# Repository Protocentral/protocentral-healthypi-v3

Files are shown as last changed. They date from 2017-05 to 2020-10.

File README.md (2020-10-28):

# ProtoCentral HealthyPi v3 HAT for Raspberry Pi

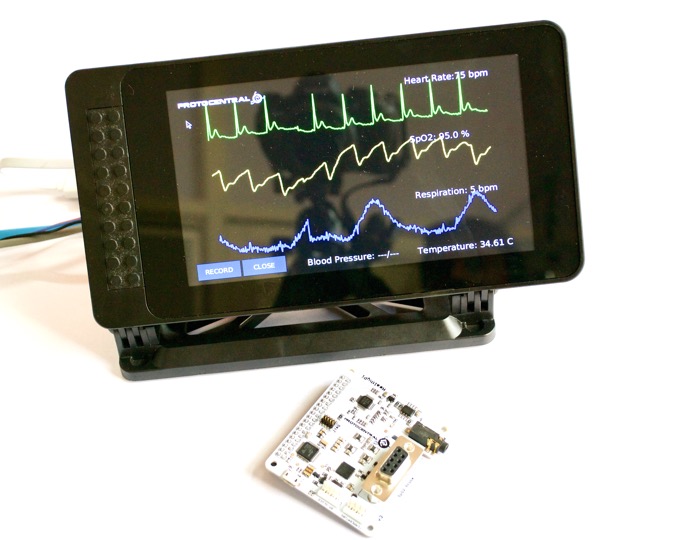
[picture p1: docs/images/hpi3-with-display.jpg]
Healthy Pi v3 HAT


HealthyPi is the first fully open-source, full-featured vital sign monitor. Using the Raspberry Pi as its computing and display platform, the HealthyPi add-on HAT turns the Raspberry Pi into a vital sign monitoring system.

If you don't already have one, you can now buy HealthyPi from any of the following places:

* [Crowd Supply](https://www.crowdsupply.com/protocentral/healthypi-v3)
* [ProtoCentral India (Worldwide)](https://www.protocentral.com/open-source-health/1252-healthypi-v3-complete-kit-includes-raspberry-pi.html)
* [DigiKey](https://www.digikey.in/product-detail/en/crowd-supply-inc/CS-HEALTHYPI-01/1848-1035-ND)
* [Mouser](https://www.mouser.in/ProductDetail/392-CS-HEALTHYPI-01)

Repository Contents
-------------------
* **/firmware** - Atmel studio  and aduino example sketches.
* **/Hardware** - All Eagle design files (.brd, .sch)
* **/extras** - includes the datasheet
* **/gui** - HealthyPi GUI for Raspberry Pi and PC
* **/docs** - Documentation

Getting Started (On Raspberry Pi):
----------------------------------

### For getting started videos and tutorials, please go to [http://healthypi.protocentral.com](http://healthypi.protocentral.com)

Mount ProtoCentral's HealthyPi-v3 HAT carefully onto the Raspberry Pi Board's GPIO Pins. Connect this setup with the Raspberry Pi's Display or a HDMI Monitor. The HAT communicates with Raspberry Pi using UART interface on the GPIO pin header. Connect the ECG electrodes and SPO2 Probe to the ProtoCentral's Healthy PI Hat.

It's now easy to get started with our brand-new installation script. Just follow the following steps on your Raspberry Pi.

To start, open up the terminal window (Menu -> Accessories -> Terminal) on Raspbian running on your Raspberry Pi:

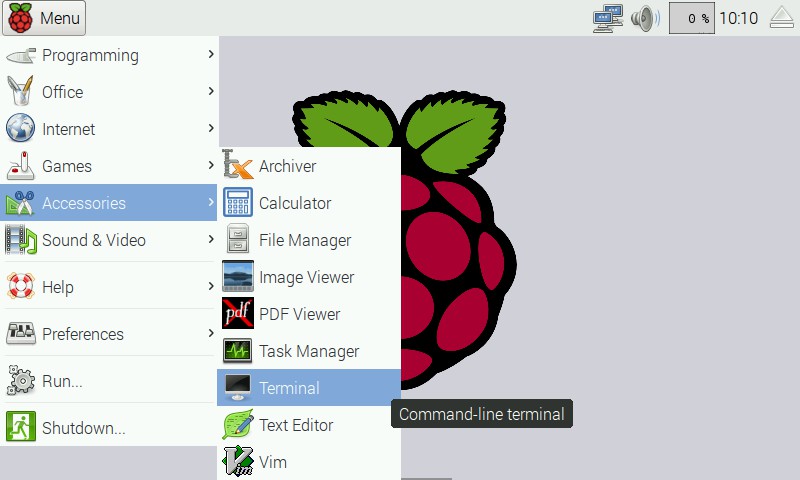
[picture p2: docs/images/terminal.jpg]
Open the terminal


In the terminal window, type the following lines.

```bash
curl -sS http://pi.protocentral.com/hpi3.sh | sudo bash
```

It really is as simple as that !!

This code will install all the required overlays, configuration and application files to get the Healthy Pi up and running.

After the script reboots, you should be able to see the GUI display on the screen

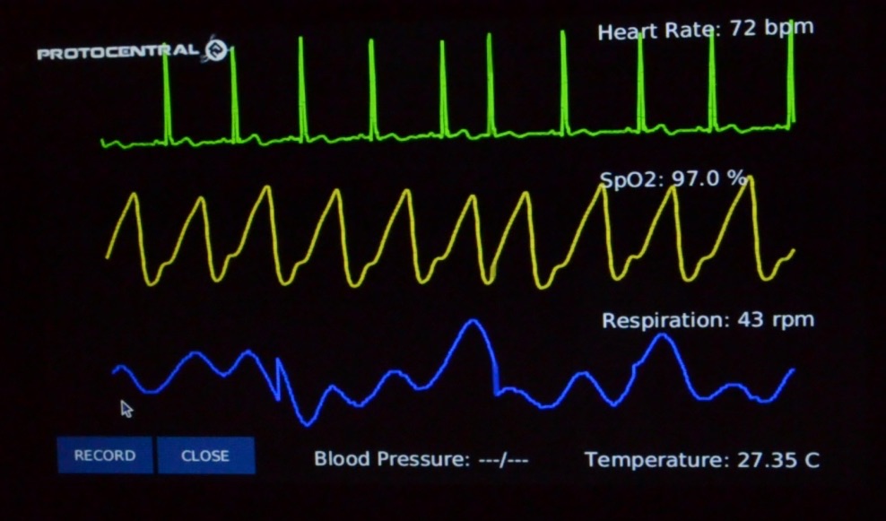
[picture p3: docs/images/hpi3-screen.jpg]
GUI in Processing


### This completes the install!

If the above script does not work for you and would like to do a manual installation or would like to customize the code, check out [Advanced HealthyPi] (/docs/advanced-healthypi.md).

Using the HealthyPi GUI on Windows, MacOS and Linux
---------------------------------------------------
The HealthyPi board now streams the same data on the on-board USB port. This allows you to get the same data that goes to the Raspberry Pi, now on your desktop PC as well.

Java 8 is required on all platforms for running the processing-based GUI application. You can download Java for your platform from the following link.

[https://java.com/en/download/](https://java.com/en/download/)

#### Installing drivers (only for Windows)

HealthyPi uses the same drivers as an Arduino Zero. Once plugged in to the USB port, the device would be recognized as an "Unknown Device". You can locate the device is the Windows Device Manager and manually install the drivers provided in the "drivers" folder in the Windows Executable ZIP archive provided.

MacOS and Linux do not need any drivers to be installed.

### Processing GUI Installation

Download the zip file containing the executable files from the releases section for 32-bit/64-bit Windows. If you do not know if you have a 64-bit or 32-bit computer, please download the 32-bit version.

[Download the latest GUI for HealthyPi](https://github.com/Protocentral/protocentral-healthypi-v3/releases/latest)

Simply download the appropriate file for your operating system, unzip the contents and run the executable program contained in it.

### For more documentation, videos and tutorials, please go to [http://healthypi.protocentral.com](http://healthypi.protocentral.com)

License Information
===================

This product is open source! Both, our hardware and software are open source and licensed under the following licenses:

Hardware
---------

**All hardware is released under [Creative Commons Share-alike 4.0 International](http://creativecommons.org/licenses/by-sa/4.0/).**


You are free to:

* Share — copy and redistribute the material in any medium or format
* Adapt — remix, transform, and build upon the material for any purpose, even commercially.
The licensor cannot revoke these freedoms as long as you follow the license terms.

Under the following terms:

* Attribution — You must give appropriate credit, provide a link to the license, and indicate if changes were made. You may do so in any reasonable manner, but not in any way that suggests the licensor endorses you or your use.
* ShareAlike — If you remix, transform, or build upon the material, you must distribute your contributions under the same license as the original.

Software
--------

**All software is released under the MIT License(http://opensource.org/licenses/MIT).**

THE SOFTWARE IS PROVIDED "AS IS", WITHOUT WARRANTY OF ANY KIND, EXPRESS OR IMPLIED, INCLUDING BUT NOT LIMITED TO THE WARRANTIES OF MERCHANTABILITY, FITNESS FOR A PARTICULAR PURPOSE AND NONINFRINGEMENT. IN NO EVENT SHALL THE AUTHORS OR COPYRIGHT HOLDERS BE LIABLE FOR ANY CLAIM, DAMAGES OR OTHER LIABILITY, WHETHER IN AN ACTION OF CONTRACT, TORT OR OTHERWISE, ARISING FROM, OUT OF OR IN CONNECTION WITH THE SOFTWARE OR THE USE OR OTHER DEALINGS IN THE SOFTWARE.

Please check [*LICENSE.md*](LICENSE.md) for detailed license descriptions.

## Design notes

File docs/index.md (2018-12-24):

---
layout: page
homepage: true
---

Healthy Pi Hat

HealthyPi is the first fully open-source, full-featured vital sign monitor. Using the Raspberry Pi as its computing and display platform, the HealthyPi add-on HAT turns the Raspberry Pi into a vital sign monitoring system.

If you don't already have one, you can now buy HealthyPi from any of the following places:

* [Crowd Supply](https://www.crowdsupply.com/protocentral/healthypi-v3)
* [ProtoCentral USA](https://protocentral.us/products/13-healthypi-v3-hat-kit-for-raspberry-pi.html)
* [ProtoCentral India (Worldwide)](https://www.protocentral.com/open-source-health/1252-healthypi-v3-complete-kit-includes-raspberry-pi.html)
* [DigiKey](https://www.digikey.in/product-detail/en/crowd-supply-inc/CS-HEALTHYPI-01/1848-1035-ND)
* [Mouser](https://www.mouser.in/ProductDetail/392-CS-HEALTHYPI-01)

# Repository Contents
-------------------
* **/firmware** - Atmel studio and Arduino example sketches.
* **/Hardware** - All Eagle design files (.brd, .sch)
* **/extras** - includes the datasheet
* **/gui** - HealthyPi GUI for Raspberry Pi and PC
* **/docs** - Additional Documentation

# Getting Started with HealthyPi

The HealthyPi was designed with not just one application in mind, but a variety of them. While it does function as a vital sign monitor for traditional patient monitoring applications, it can also be used for several other applications. You can use it with a Raspberry Pi using a display; use it with a Raspberry Pi with the official touchscreen using our “Complete Kit,” or you can use it standalone by connecting it to any computer’s USB port. The software is compatible across all platforms.

## Getting started with the HealthyPi Complete Kit

If you have purchased the "HealthyPi Complete Kit", then it would already come with a Raspberry Pi and microSD storage with all the HealthyPi software pre-loaded and configured on it. Just plug it in and it should work.

You would still need to assemble the display enclosure and the display stand for the provided [SmartiPi Touch Case](https://smarticase.com/collections/all/products/smartipi-touch). The SmartiPi Touch that comes included with the HealthyPi kit is already partly assembled. Check out the below video for instructions on how to assemble the kit.

<iframe src="https://player.vimeo.com/video/225759990" width="640" height="360" frameborder="0" webkitallowfullscreen mozallowfullscreen allowfullscreen></iframe>

## Getting started with HealthyPi on Raspberry Pi

If you have a Raspberry Pi setup already available, just follow the following steps on your Raspberry Pi. You will need a monitor and a keyboard/mouse and the Raspberry Pi should be running Raspbian before proceeding with HealthyPi installation. To find out how to install Raspbian check out this great tutorial on Raspberry Pi's official site.

The following video shows you how to connect the HealthyPi to a Raspberry Pi.

<iframe src="https://player.vimeo.com/video/226236581" width="640" height="360" frameborder="0" webkitallowfullscreen mozallowfullscreen allowfullscreen></iframe>

After completing the steps shown in the video, open up the terminal window (Menu -> Accessories -> Terminal) on Raspbian running on your Raspberry Pi:

Open the terminal

In the terminal window, type the following lines.

```bash
curl -sS http://pi.protocentral.com/hpi3.sh | sudo bash
```

Follow the instructions shown carefully, this will download and install all that is required to get the HealthyPi running.

It really is as simple as that. This code will install all the required overlays, configuration and application files to get the Healthy Pi up and running.

After the script reboots your Raspberry Pi, you should be able to see the GUI display the sensor outputs in real-time on the screen.

GUI in Processing

**This completes the install!**

## Getting started with the HealthyPi GUI on Windows, MacOS and Linux

The HealthyPi board now streams the same data on the on-board USB port. This allows you to get the same data that goes to the Raspberry Pi, now on your desktop PC as well.

<iframe src="https://player.vimeo.com/video/225754981" width="640" height="360" frameborder="0" webkitallowfullscreen mozallowfullscreen allowfullscreen></iframe>

*Java 8 is required on all platforms for running the processing-based GUI application. You can download Java for your platform from the following link.*

[https://java.com/en/download/](https://java.com/en/download/)

### Installing drivers (only for Windows)

HealthyPi uses the same drivers as an Arduino Zero. Once plugged in to the USB port, the device would be recognized as an "Unknown Device". You can locate the device is the Windows Device Manager and manually install the drivers provided in the "drivers" folder in the Windows Executable ZIP archive provided.

MacOS and Linux do not need any drivers to be installed.

### Processing GUI Installation

Download the zip file containing the executable files from the following links for 32-bit/64-bit Windows. If you do not know if you have a 64-bit or 32-bit computer, try with the 32-bit version.

[Download the latest release here](https://github.com/Protocentral/protocentral-healthypi-v3/releases/latest)

Simply download the appropriate file for your operating system, unzip the contents and run the executable program contained in it. On desktop operating systems, you will have to choose the correct port name assigned to the HealthyPi by USB. Simply select the port from the dropdown on the top and port should be opened.

*Note: On MacOS, if you see an error saying "app is damaged", please follow the steps given in https://support.apple.com/en-us/HT202491 .This is a known issue with Processing on MacOS.*

# Connecting the sensors

## Connecting the ECG/Respiration Electrodes

A 3-electrode cable along with a standard stereo jack is provided along with the shield to connect the electrodes to the  board.
The other side of the electrode connector would connect to snap-on electrodes attached to the body. For testing purposes, you can use an ECG simulator to provide inputs to the board.

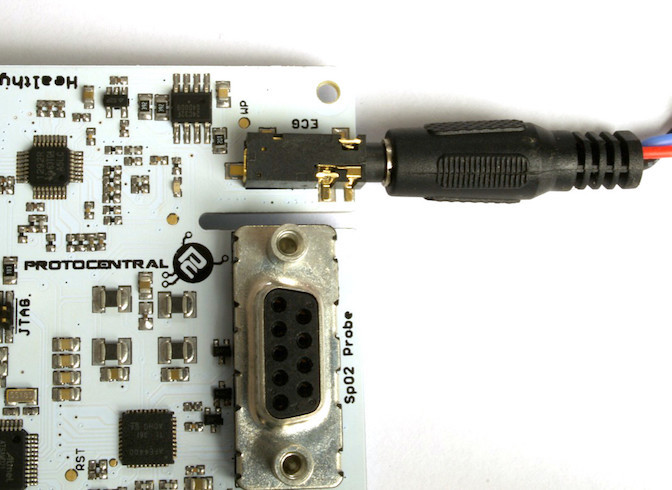
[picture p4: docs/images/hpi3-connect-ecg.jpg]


**Important Warning:**
When connecting the electrodes to the body, it is safer to disconnect the mains power source to the Arduino. For example, if  you are using the Arduino along with a laptop, disconnecting the battery charger from the laptop would be a safe option.

Place the electrodes on the body in these positions to get the best signal. However, placing it in other positions on the chest would work as well with differing ECG signal patterns. For getting respiration using the [Impedance Pneumography](http://www.ti.com/lit/an/sbaa181/sbaa181.pdf), it's best to wear them on the chest as given in the figure below to get the best signal.

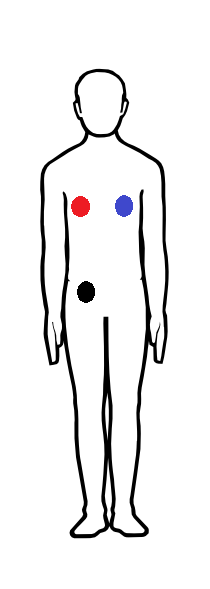
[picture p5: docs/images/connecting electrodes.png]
Wearing the Electrode


## Connecting the Pulse Oximetry Probe

[Pulse oximetry] is an optical method of non-invasively measuring the oxygen content in the blood. This is achieved with the help of a finger-clip probe that contains some LEDs on one side of the clip and a photo-detector on the other side.

The LEDs emit light in the red and IR wavelengths. Some of these are absorbed by the blood and the rest is transmitted through to the other side of  the finger, which is is picked up by the photo-detector. The Pulse Oximetry front-end measures this variance in the transmitted light intensity to display the Photoplethysmogram (PPG) signal. SpO2 is a computed value derived from the Red and IR PPG signal.

To start measuring, simply plug-in the provided SpO2 finger-clip probe to the DB9 connector on the HealthyPi main board. If the probe is properly plugged in, you should see a Red glow inside the probe.

[Photo of plugging in the DB9 connector]

## Connecting the temperature sensor

A digital human body temperature sensor based on the MAX30205 from Maxim Integrated is provided. This sensor provides direct, calibrated temperature values over a digital I2C interface. This comes pre-connected with the HealthyPi through a simple screw-terminal based connector and a cable for maximum flexibility.

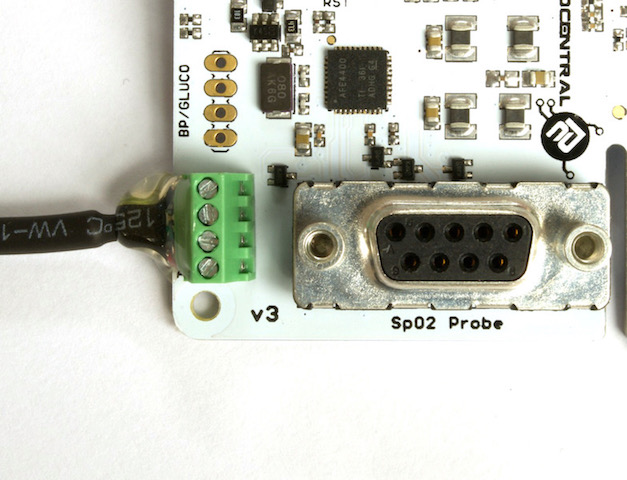
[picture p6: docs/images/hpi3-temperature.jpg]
Temperature sensor


If you ever remove the sensor and wish to connect it back to the HealthyPi, please wire it in the sequence shown in the following picture.

[Photo of temperature sensor connector with color codes]

# Updating the firmware

It is important to always keep your firmware up-to-date for best results. We keep adding changes, bug fixes and enhancements as and when we do updates. HealthyPi will be continued to be developed and new features added.

Be on the lookout for new firmware releases on our Github releases page at:

https://github.com/Protocentral/protocentral-healthypi-v3/releases

To install the new firmware and/or try out your own firmware, check out new [Guide to Firmware Upgrades](firmware-upgrades.md).

# Streaming Packet Format

The HealthyPi sends data out on the serial port in the following packet format.

 Offset| Byte Value                 | Description   
--------|---------------------------|---------------
 0     | 0x0A                       | Start of frame
 1     | 0xFA                       | Start of frame
 2     | Payload Size LSB           |               
 3     | Payload Size MSB           |               
 4     | Protocol version           | (currently 0x02)
 5-6   | ECG Value                  | Signed int 16,LSB first
 7-8   | Respiration Value          | Signed int 16,LSB first
 9-12  | PPG IR Value               | Signed int 32, LSB first
 13-16 | PPG Red Value              | Signed int 32, LSB first
 17-18 | Temperature                | Signed int 16, LSB first
 19    | Respiration Rate           | Unsigned int 8
 20    | SpO2                       | Unsigned int 8
 21    | Heart Rate                 | Unsigned int 8
 21-23 | BP (not implemented)       | Not implemented yet
 24    | SpO2 and ECG lead status   |
 25    | 0x00                       | Footer
 26    | 0x0B                       | End of Frame

# License Information

This product is open source! Both, our hardware and software are open source and licensed under the following licenses:

## Hardware

All hardware is released under [Creative Commons Share-alike 4.0 International](http://creativecommons.org/licenses/by-sa/4.0/).



## Software

All software is released under the MIT License(http://opensource.org/licenses/MIT).

Please check [*LICENSE.md*](LICENSE.md) for detailed license descriptions.

THE SOFTWARE IS PROVIDED "AS IS", WITHOUT WARRANTY OF ANY KIND, EXPRESS OR IMPLIED, INCLUDING BUT NOT LIMITED TO THE WARRANTIES OF MERCHANTABILITY, FITNESS FOR A PARTICULAR PURPOSE AND NON-INFRINGEMENT. IN NO EVENT SHALL THE AUTHORS OR COPYRIGHT HOLDERS BE LIABLE FOR ANY CLAIM, DAMAGES OR OTHER LIABILITY, WHETHER IN AN ACTION OF CONTRACT, TORT OR OTHERWISE, ARISING FROM, OUT OF OR IN CONNECTION WITH THE SOFTWARE OR THE USE OR OTHER DEALINGS IN THE SOFTWARE.

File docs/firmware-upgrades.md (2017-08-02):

# Upgrading HealthyPi v3 Firmware

All HealthyPi v3 boards come **pre-installed** with the Arduino Zero bootloader and the current release Arduino-based code. This means that you no longer need a JTAG programmer or Atmel Studio or similar toolchain to customize the code on the SAMD21 microcontroller on the board.

In addition, the new Arduino-based HealthyPi v3 firmware now **streams over USB** the same data sent to the Raspberry Pi's UART pins. This now means that the HealthyPi works not just with a Raspberry Pi, but any Windows/MAC/Linux machine that supports Java and Processing.

To upgrade the firmware, simply following these steps to get started:

### Step 1: Install the Arduino IDE

Download and install the latest version of the Arduino IDE for your corresponding platform from the following Page.

[Arduino Downloads Page at https://www.arduino.cc/en/Main/Software](https://www.arduino.cc/en/Main/Software)

### Step 2: Install support for the Arduino Zero (Atmel SAMD21 MCU)

Plug in the HealthyPI to your PC through the USB cable provided and follow the instructions on Arduino website for getting started with the Arduino Zero. When connected to a computer, your HealthyPi will behave exactly like an Arduino Zero does.

[Install support for Arduino Zero](https://www.arduino.cc/en/Guide/ArduinoZero)

### Step 3: Open the HealthyPi code in Arduino

Download the latest code from the releases section of the HealthyPi v3 Github repository at https://github.com/Protocentral/protocentral-healthypi-v3/releases

From this page, download the "healthypi-firmware.zip" file under the **latest available release**.

Once downloaded, unzip the file and in Arduino open the ".ino" file from the unzipped folder.

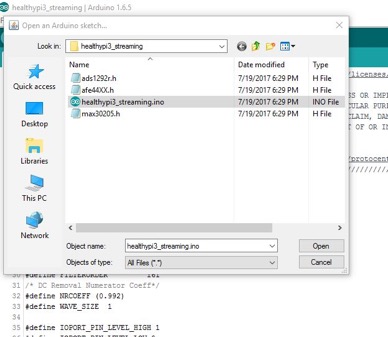
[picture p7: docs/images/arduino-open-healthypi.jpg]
Open in Arduino


### Step 4: Upload the program

Click the "Upload" button on the Arduino IDE to compile and upload the firmware.

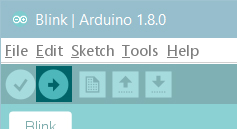
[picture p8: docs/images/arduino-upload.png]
Upload to Arduino


If all goes well, you should see an "Done Uploading" or similar message.

### Step 5: Start hacking

Feel to hack away at the code and try out things. Submit an issue on our Github site (https://github.com/Protocentral/protocentral-healthypi-v3/issues) if you think you've run into a bug or if there's something you'd like to see added.

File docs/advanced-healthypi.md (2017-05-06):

Advanced HealthyPi
==================
This section is for those who want to do a manual installation of HealthyPi, those who want to modify with the code and generally play with the hardware.

For the simple way to setup HealthyPi on Raspberry Pi, check out the [getting started guide](https://github.com/protocentral/healthypi).

You can buy [HealthyPi at ProtoCentral](https://www.protocentral.com/healthypi)

Setting up Raspberry Pi for UART Communication
----------------------------------------------
The following are the steps involved to get Raspberry Pi ready for a patient monitor.

###Step 1 : Install and Update the OS

* Install the Raspbian OS in Raspberry Pi. The image file can be downloaded from the [Raspberry Pi's official website](https://www.raspberrypi.org/downloads/).

* Once the installation finishes, update the system with the following command in the Terminal:
		
		sudo apt-get update
		sudo apt-get upgrade

###Step 2 : Enable the UART0 device tree overlay

As the ProtoCentral's Healthy Pi Hat communicates with the Raspberry Pi board via GPIO 14/15 which on the Model B, B+ and Pi2 is mapped to UART0. However on the Pi3 these pins are mapped to UART1 since UART0 is now used for the bluetooth module. As UART1 is not stable because it is dependent to clock speed which can change with the CPU load, we have to disable the Bluetooth module and map UART1 back to UART0 (tty/AMA0).

* Run the following command

		sudo nano /boot/config.txt

* Add this line to the end of the file

		dtoverlay=pi3-miniuart-bt

###Step 3 : Disable Serial command line console

* To disable the Serial Console edit the file using

		sudo nano /boot/cmdline.txt 

* Remove the word phase "console=serial0,115200" or "console=ttyAMA0,115200".

* Save the file and close

###Step 4 : Reboot your Raspberry Pi

* Now your Pi is ready to integrate with ProtoCentral's Healthy Pi Hat.

HealthyPi GUI based on Processing
---------------------------------

[Processing](https://processing.org/) has been used to develop the visualization software for the HealthyPi. 

Processing is an open source framework based on Java. The following are the steps to get the visualization software ready for patient monitor:

###Step 1 : Download Processing IDE for your HOST COMPUTER operating system

a. Latest Version of the Processing IDE can be downloaded from the following link:

[Download Processing](https://processing.org/download/?processing)

b. Unzip and install the file once downloaded.

###Step 2 : Download the Processing code for the HealthyPi GUI

a. Download the necessary files & directories or clone to your desktop from GitHub.

b. Unzipping the archive should make a folder by name HealthyPi that contains the visualisation code.

c. Locate the Processing sketchbook directory on your computer. This should have been created automatically when you installed processing. Depending on your operating system, the path will be as follows:

* On Windows : C:/My Documents/Processing
* On MAC : /Users/your_user_name/Documents/Processing
* On Linux : /Home/your_user_name/sketchbook/

**Note:** This directory appears as "Processing" on Windows/Mac, and goes by the name "Sketchbook" on Linux. Create a subdirectory by name "libraries if one doesn't exist already.

d. From the above mentioned "HealthyPi" directory Copy/Move the contents of the HealthyPi/Processing/HealthyPi folder to the Processing sketchbook directory which is also mentioned above (Locate the Processing sketchbook)

e. Finally, copy the "controlP5 & G4P" folders from HealthyPi/Processing/libraries/ and paste them into the libraries directory of your Processing sketchbook.

###Step 3 : Upload the Processing code Raspberry Pi

* In Processing IDE, Select "Tools" from the menu and choose, "Add tools".

* Select "Upload To Pi" tool and click Install button which is present in the button right corner as shown in the below image.

![Upload To Pi in Processing]
(https://github.com/Protocentral/HealthyPi/blob/master/extras/Images/Upload_To_Pi.png)

* Now, connect your raspberry pi to the internet with the same network as your laptop is connected.

* Select "Tools" menu and choose "Upload to Pi" option from the list.

* If any error occured in uploading the code, check for the internet connection and repeat the process.

Firmware:
---------

The board is pre-loaded with the firmware which works stand alone with the Rpi without any firmware development or loading required. 

However, if you want to edit the firmware, you can follow the steps in this [document] (/docs/recompiling-firmware.md)

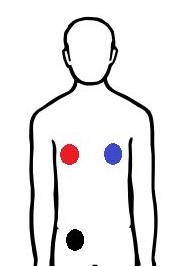
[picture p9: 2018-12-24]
docs/images/ecg cable connection.jpg

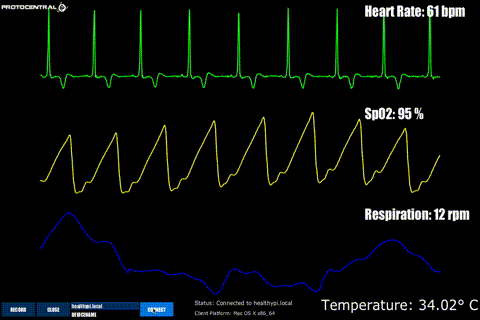
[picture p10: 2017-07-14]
docs/images/hpi3-tcp-screen.gif

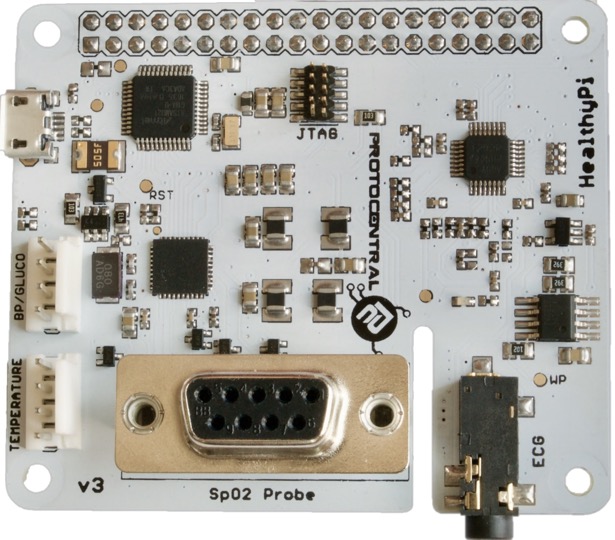
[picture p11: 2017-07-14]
docs/images/hpi-3-top.jpg

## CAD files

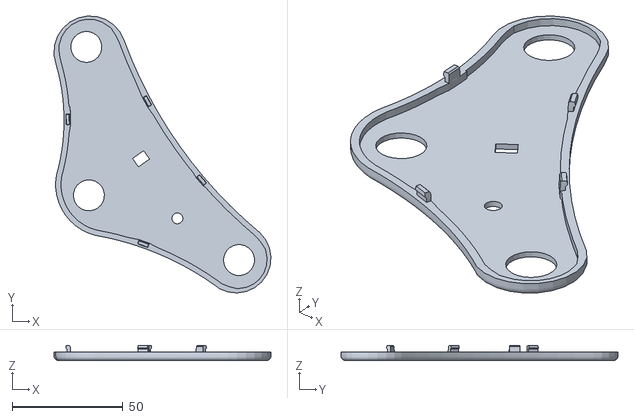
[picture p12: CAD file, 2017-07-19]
gui/healthypi3_gui_tcp/data/Fit Patch Assly Organic Covers - 33.stl
98.1 x 125.2 x 6.81

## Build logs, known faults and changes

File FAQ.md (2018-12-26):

## How to use the sensors?

The Healthy Pi v3 board itself has provisions for biometric sensors that can detect human vital signs. Using these sensors in an accurate way can play a crucial role in getting the correct readings. Let’s take a closer look.

1) SPO2 probe

The Spo2 probe also known as the Saturation of Peripheral Oxygen is a handy probe that can help to detect the level of Oxygen in the blood.

Tip: 
* Gently open the probe and place your index finger inside.
* To ensure that the finger is placed in the middle of the probe.
* Correct placement of the finger can ensure accurate readings.
* You can also ensure that the probe is not exposed to excess light. It can be kept in the dark.

2) ECG Electrodes

ECG or Electrocardiogram helps to measure the electrical activity of the heart. To measure this a set of electrodes are placed on different parts of the body.

![ecg cable connection](images//ecg cable connection.jpg]

* Red - Attach the red electrode to the right side of your chest.
* Blue - Attach the blue electrode to the left side of your chest. 
* Black - Attach the black electrode to the right side of your lower waist.

3) Temperature sensor

The MAX 30205 body temperature sensor helps to detect the body temperature through the skin using the sensor.

Tip:
* Hold the temperature sensor using the index finger and the thumb and press gently. You can find the values changing in the lower section of the screen.

## Powering up the Healthy Pi

Healthy Pi offers some very flexible options when it comes to its use as well as its applications. The very basic step to get started with the board is by powering it up. The board needs a charge of 5V to get powered up. There are some options to powering up your board. They are:-

* Using a Battery HAT

    The board can be attached with a Battery HAT. The basic 5V can be provided by the Battery HAT that is also rechargeable through the USB port.

* Using Power banks

    The board can also be powered using Power banks that are actually easier and handy in carrying around.

* Using USB cables

     The board can be connected to any system/device using the USB cable. This would power up the board in standalone operations.

## Troubleshooting

### With the Display
| Issue | Solution |
|---|---|
| If everything is assembled but the display is blank? | Check the “Y” cable provided. |
| | Ensure that the boards are plugged in. |
| | There may be loose connection in the connecting cable from display to Raspberry Pi3 |
| Raspberry Pi is powering up but still rebooting? | There might be insufficient power. Check the power source. |
| | The sd card may be corrupted( Check for preloaded software) |
| | Use the power adapter provided in the kit. |
| Raspberry Pi booted but UI not starting up? | The operating system might not be upgraded. |
| UI is stable but, nothing is plotted? | Healthy Pi board is not properly plugged in. |
| | Firmware may be corrupted, needs to be reloaded. |
| The vital parameters are noisy. Why? | Check the power source, use the adapter provided. |
| | The sensors need to be properly connected to the Healthy Pi board. |
| | The sensors need to be securely attached to the body. |

### Healthy Pi with the Raspberry Pi

| Issue | Solution |
|---|---|
| Which OS needs to be used? | The Raspbian software with the latest release. |
| How can you set up the UI? | Install the OS, enter the following in the terminal |
| | curl -sS http://pi.protocentral.com/pi.sh | sudo bash |
| Why does error occur once the command runs? | Ensure that it runs in the Superuser mode. |
| What if the UI opens, the screen is blank and no plotting? | Check the Healthy Pi board connection. If the firmware is outdated or corrupted, reload it. |
| | Healthy Pi board communicates with Raspberry Pi OSM serial interface, ensure the serial lines are free. |
| | ( Note: On the display screen, observe the temperature values. If there are changes then it is working) |
| What if the signal quality is bad or the vitals are incorrect? | Check the power adapter, use an isolated power supply to power up the Hpi. |
| | Check the sensor connection 
 
### Standalone Healthy Pi with Desktop

| Issue | Solution |
|---|---|
| The board is plugged in but the USB is not getting detected. | Healthy Pi board is preloaded with the Arduino M0 bootloader which is pre-installed. However, check the following: |
| | Check the USB cable |
| | Change the USB port |
| | Check whether the Power LED on the board glows. |
| | If the above does not work then check it again with another PC. |
| If the USB is enumerated then when can you see the output? | Download the latest release file, run the .exe file. |
| The application is downloaded but it will not open? | Give a check on whether it is the latest Java download from this link https://java.com/en/download/ |
| The application opens but there is a “port error”? | Setup up virtual COM port of the Healthy Pi |
| The application is blank/ No streaming | Firmware may be outdated, needs to be upgraded. |
| Vitals are unclear or noisy | Check the sensors if they are connected |
| | Remove the AC adapter from the laptop, as it adds to the noise. 

*Please submit an [issue on Github](https://github.com/Protocentral/protocentral-healthypi-v3/issues/new) if you face any problems with the HealthyPi.*

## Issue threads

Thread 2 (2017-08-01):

Unreliable readings from the ECG

DRMacIver, 2017-08-01:
Hi,

I'm just experimenting with my new HealthyPi, but unfortunately I don't seem to be able to get at all reliable results for heart rate from the ECG. It frequently drops to zero for an extended period of time (in which I'm pretty sure my heart is not stopping), and often significantly under reports a lot of the rest of the time when compared to another presumed-good heart rate monitor I have (a v3.5 Contec CMS50F Pulse Oximeter).

This *could* be a sensor placement issue, but I don't think so - even if I stay very still the heart rate oscillates between extended periods of zero and apparently normal reading, and I've tried several sensor placements and it didn't seem to improve matters much.

Any idea what might be going on? Is there more information I can provide to help debugging?

protocentralashwin, 2017-08-01:
@DRMacIver Thank you.

In the original GUI which we had made, there we were a few bugs which were not fixed. A value of zero indicates Lead-off (contact) conditions. This is supposed to come as a message.

We are also tweaking the ECG algorithm a bit more to remove motion artifacts. We will have a new release of the firmware and the GUI by tomorrow. Please check again after the release.

I'm leaving this issue open so that you can try out after tomorrow and give your feedback.

DRMacIver, 2017-08-01:
> In the original GUI which we had made, there we were a few bugs which were not fixed. A value of zero indicates Lead-off (contact) conditions.

Just to make sure I understand, that means that when a value of zero is showing one of the pads attached to me is not getting a good contact? Or could that just be a sign of bad placement? Is there a way to tell which sensor is not making good contact?

> Please check again after the release

Thanks, will do.

For when the release is out, are there instructions somewhere for how to update the firmware on the device? I couldn't find any.

protocentralashwin, 2017-08-01:
Lead-off means that the contact impedance is too high and a no-contact condition is assumed. Bad placement in terms of location cannot be detected, you will just get a different kind of waveform. Is it possible for you to post a screenshot of the plot you're getting?

For more information about Lead-off, this document is great: http://www.ti.com/lit/an/sbaa196a/sbaa196a.pdf

For firmware update, you can just do it through Arduino. Now that you mention it, we'll write up a document about how to do this and put that up also.

DRMacIver, 2017-08-01:
>  Is it possible for you to post a screenshot of the plot you're getting?

Sorry, I'd already taken off the ECG sensors when I saw this. I'll do a reading and screenshot it before I update the software tomorrow so I can get a before and after comparison.

protocentralashwin, 2017-08-02:
@DRMacIver We've posted the new release of the firmware. Please download it at https://github.com/Protocentral/protocentral-healthypi-v3/releases.

The guide to upgrading the firmware is also now at http://healthypi.protocentral.com/firmware-upgrades.html

Closed 2018-01-21.

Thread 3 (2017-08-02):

Thermometer is fairly slow to stabilise on a temperature

DRMacIver, 2017-08-02:
I'm testing the thermometer on my HealthyPi with an armpit reading. It seems to be taking longer than I would expect to stabilise.

When I started recording at 11:56:58 it was reporting a temperature of 29.56C (this is not the ambient temperature, so I think I had it under my armpit for about 30 seconds before I started recording). It did not report a temperature above 36C until 12:03:58 when it reported 36.02. It eventually stabilised on around 36.25C by 12:07:53, which seems a little low but is at least plausible.

It also on removal took a fairly long time to stabilise downwards. At 12:10:24 it was reporting 36.02, and seems to have stabilized on about 21.2C and first dropped below 21.5C at 12:20:45, so again about 10 minutes to update.

This seems like a long time. I've not really done a detailed analysis of temperature over time on thermometers before, but I'd typically expect a few minutes rather than ten. Is this expected behaviour?

protocentralashwin, 2017-08-02:
@DRMacIver That is definitely not right.

We did some testing on our own. The temperature sensor chip itself responds quite fast. However, to make it more usable and to avoid bringing any contact of the PCB directly with the body, we had attached it to a stainless steel button. The button is the one that seems to retain the heat and hence affects sensitivity.

Can you try by carefully removing the button from the temperature sensor PCB (the small round one)? This would for sure make it more responsive, but putting a PCB directly on the skin is not what I would recommend.

Closed 2018-02-04.

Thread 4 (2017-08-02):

Firmware compilation error on Linux

mithrandi, 2017-08-02:
The code has `#include "afe44xx.h"` but the file is named `afe44XX.h` in the archive; this will work on an OS with case-insensitive file access, but not on Linux.

protocentralashwin, 2017-08-03:
@mithrandi Thanks. Fixed the issue. Combined this file with another header file.

Closed 2017-08-03.

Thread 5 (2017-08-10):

"'sercom2' was not declared in this scope" compile error in Arduino

docmollo, 2017-08-10:
Tried compiling the streaming version of the firmware with Arduino IDE 1.8.3 on a 64-bit Fedora 25 machine. The compiler error output is below (from the IDE).

```
Arduino: 1.8.3 (Linux), Board: "Arduino/Genuino Uno"

/home/dustin/src/arduino-1.8.3/arduino-builder -dump-prefs -logger=machine -hardware /home/dustin/src/arduino-1.8.3/hardware -hardware /home/dustin/.arduino15/packages -hardware /home/dustin/src/arduino/hardware -tools /home/dustin/src/arduino-1.8.3/tools-builder -tools /home/dustin/src/arduino-1.8.3/hardware/tools/avr -tools /home/dustin/.arduino15/packages -built-in-libraries /home/dustin/src/arduino-1.8.3/libraries -libraries /home/dustin/src/arduino/libraries -fqbn=arduino:avr:uno -ide-version=10803 -build-path /tmp/arduino_build_33309 -warnings=none -build-cache /tmp/arduino_cache_685491 -prefs=build.warn_data_percentage=75 -prefs=runtime.tools.avr-gcc.path=/home/dustin/src/arduino-1.8.3/hardware/tools/avr -prefs=runtime.tools.avrdude.path=/home/dustin/src/arduino-1.8.3/hardware/tools/avr -prefs=runtime.tools.arduinoOTA.path=/home/dustin/src/arduino-1.8.3/hardware/tools/avr -verbose /home/dustin/src/healthypi-firmware/firmware/healthypi3_streaming/healthypi3_streaming.ino
/home/dustin/src/arduino-1.8.3/arduino-builder -compile -logger=machine -hardware /home/dustin/src/arduino-1.8.3/hardware -hardware /home/dustin/.arduino15/packages -hardware /home/dustin/src/arduino/hardware -tools /home/dustin/src/arduino-1.8.3/tools-builder -tools /home/dustin/src/arduino-1.8.3/hardware/tools/avr -tools /home/dustin/.arduino15/packages -built-in-libraries /home/dustin/src/arduino-1.8.3/libraries -libraries /home/dustin/src/arduino/libraries -fqbn=arduino:avr:uno -ide-version=10803 -build-path /tmp/arduino_build_33309 -warnings=none -build-cache /tmp/arduino_cache_685491 -prefs=build.warn_data_percentage=75 -prefs=runtime.tools.avr-gcc.path=/home/dustin/src/arduino-1.8.3/hardware/tools/avr -prefs=runtime.tools.avrdude.path=/home/dustin/src/arduino-1.8.3/hardware/tools/avr -prefs=runtime.tools.arduinoOTA.path=/home/dustin/src/arduino-1.8.3/hardware/tools/avr -verbose /home/dustin/src/healthypi-firmware/firmware/healthypi3_streaming/healthypi3_streaming.ino
Using board 'uno' from platform in folder: /home/dustin/src/arduino-1.8.3/hardware/arduino/avr
Using core 'arduino' from platform in folder: /home/dustin/src/arduino-1.8.3/hardware/arduino/avr
Detecting libraries used...
"/home/dustin/src/arduino-1.8.3/hardware/tools/avr/bin/avr-g++" -c -g -Os -w -std=gnu++11 -fpermissive -fno-exceptions -ffunction-sections -fdata-sections -fno-threadsafe-statics  -flto -w -x c++ -E -CC -mmcu=atmega328p -DF_CPU=16000000L -DARDUINO=10803 -DARDUINO_AVR_UNO -DARDUINO_ARCH_AVR   "-I/home/dustin/src/arduino-1.8.3/hardware/arduino/avr/cores/arduino" "-I/home/dustin/src/arduino-1.8.3/hardware/arduino/avr/variants/standard" "/tmp/arduino_build_33309/sketch/healthypi3_streaming.ino.cpp" -o "/dev/null"
"/home/dustin/src/arduino-1.8.3/hardware/tools/avr/bin/avr-g++" -c -g -Os -w -std=gnu++11 -fpermissive -fno-exceptions -ffunction-sections -fdata-sections -fno-threadsafe-statics  -flto -w -x c++ -E -CC -mmcu=atmega328p -DF_CPU=16000000L -DARDUINO=10803 -DARDUINO_AVR_UNO -DARDUINO_ARCH_AVR   "-I/home/dustin/src/arduino-1.8.3/hardware/arduino/avr/cores/arduino" "-I/home/dustin/src/arduino-1.8.3/hardware/arduino/avr/variants/standard" "-I/home/dustin/src/arduino-1.8.3/hardware/arduino/avr/libraries/SPI/src" "/tmp/arduino_build_33309/sketch/healthypi3_streaming.ino.cpp" -o "/dev/null"
"/home/dustin/src/arduino-1.8.3/hardware/tools/avr/bin/avr-g++" -c -g -Os -w -std=gnu++11 -fpermissive -fno-exceptions -ffunction-sections -fdata-sections -fno-threadsafe-statics  -flto -w -x c++ -E -CC -mmcu=atmega328p -DF_CPU=16000000L -DARDUINO=10803 -DARDUINO_AVR_UNO -DARDUINO_ARCH_AVR   "-I/home/dustin/src/arduino-1.8.3/hardware/arduino/avr/cores/arduino" "-I/home/dustin/src/arduino-1.8.3/hardware/arduino/avr/variants/standard" "-I/home/dustin/src/arduino-1.8.3/hardware/arduino/avr/libraries/SPI/src" "-I/home/dustin/src/arduino-1.8.3/hardware/arduino/avr/libraries/Wire/src" "/tmp/arduino_build_33309/sketch/healthypi3_streaming.ino.cpp" -o "/dev/null"
"/home/dustin/src/arduino-1.8.3/hardware/tools/avr/bin/avr-g++" -c -g -Os -w -std=gnu++11 -fpermissive -fno-exceptions -ffunction-sections -fdata-sections -fno-threadsafe-statics  -flto -w -x c++ -E -CC -mmcu=atmega328p -DF_CPU=16000000L -DARDUINO=10803 -DARDUINO_AVR_UNO -DARDUINO_ARCH_AVR   "-I/home/dustin/src/arduino-1.8.3/hardware/arduino/avr/cores/arduino" "-I/home/dustin/src/arduino-1.8.3/hardware/arduino/avr/variants/standard" "-I/home/dustin/src/arduino-1.8.3/hardware/arduino/avr/libraries/SPI/src" "-I/home/dustin/src/arduino-1.8.3/hardware/arduino/avr/libraries/Wire/src" "/home/dustin/src/arduino-1.8.3/hardware/arduino/avr/libraries/SPI/src/SPI.cpp" -o "/dev/null"
"/home/dustin/src/arduino-1.8.3/hardware/tools/avr/bin/avr-g++" -c -g -Os -w -std=gnu++11 -fpermissive -fno-exceptions -ffunction-sections -fdata-sections -fno-threadsafe-statics  -flto -w -x c++ -E -CC -mmcu=atmega328p -DF_CPU=16000000L -DARDUINO=10803 -DARDUINO_AVR_UNO -DARDUINO_ARCH_AVR   "-I/home/dustin/src/arduino-1.8.3/hardware/arduino/avr/cores/arduino" "-I/home/dustin/src/arduino-1.8.3/hardware/arduino/avr/variants/standard" "-I/home/dustin/src/arduino-1.8.3/hardware/arduino/avr/libraries/SPI/src" "-I/home/dustin/src/arduino-1.8.3/hardware/arduino/avr/libraries/Wire/src" "/home/dustin/src/arduino-1.8.3/hardware/arduino/avr/libraries/Wire/src/Wire.cpp" -o "/dev/null"
"/home/dustin/src/arduino-1.8.3/hardware/tools/avr/bin/avr-g++" -c -g -Os -w -std=gnu++11 -fpermissive -fno-exceptions -ffunction-sections -fdata-sections -fno-threadsafe-statics  -flto -w -x c++ -E -CC -mmcu=atmega328p -DF_CPU=16000000L -DARDUINO=10803 -DARDUINO_AVR_UNO -DARDUINO_ARCH_AVR   "-I/home/dustin/src/arduino-1.8.3/hardware/arduino/avr/cores/arduino" "-I/home/dustin/src/arduino-1.8.3/hardware/arduino/avr/variants/standard" "-I/home/dustin/src/arduino-1.8.3/hardware/arduino/avr/libraries/SPI/src" "-I/home/dustin/src/arduino-1.8.3/hardware/arduino/avr/libraries/Wire/src" "/home/dustin/src/arduino-1.8.3/hardware/arduino/avr/libraries/Wire/src/utility/twi.c" -o "/dev/null"
Generating function prototypes...
"/home/dustin/src/arduino-1.8.3/hardware/tools/avr/bin/avr-g++" -c -g -Os -w -std=gnu++11 -fpermissive -fno-exceptions -ffunction-sections -fdata-sections -fno-threadsafe-statics  -flto -w -x c++ -E -CC -mmcu=atmega328p -DF_CPU=16000000L -DARDUINO=10803 -DARDUINO_AVR_UNO -DARDUINO_ARCH_AVR   "-I/home/dustin/src/arduino-1.8.3/hardware/arduino/avr/cores/arduino" "-I/home/dustin/src/arduino-1.8.3/hardware/arduino/avr/variants/standard" "-I/home/dustin/src/arduino-1.8.3/hardware/arduino/avr/libraries/SPI/src" "-I/home/dustin/src/arduino-1.8.3/hardware/arduino/avr/libraries/Wire/src" "/tmp/arduino_build_33309/sketch/healthypi3_streaming.ino.cpp" -o "/tmp/arduino_build_33309/preproc/ctags_target_for_gcc_minus_e.cpp"
"/home/dustin/src/arduino-1.8.3/tools-builder/ctags/5.8-arduino11/ctags" -u --language-force=c++ -f - --c++-kinds=svpf --fields=KSTtzns --line-directives "/tmp/arduino_build_33309/preproc/ctags_target_for_gcc_minus_e.cpp"
Compiling sketch...
"/home/dustin/src/arduino-1.8.3/hardware/tools/avr/bin/avr-g++" -c -g -Os -w -std=gnu++11 -fpermissive -fno-exceptions -ffunction-sections -fdata-sections -fno-threadsafe-statics -MMD -flto -mmcu=atmega328p -DF_CPU=16000000L -DARDUINO=10803 -DARDUINO_AVR_UNO -DARDUINO_ARCH_AVR   "-I/home/dustin/src/arduino-1.8.3/hardware/arduino/avr/cores/arduino" "-I/home/dustin/src/arduino-1.8.3/hardware/arduino/avr/variants/standard" "-I/home/dustin/src/arduino-1.8.3/hardware/arduino/avr/libraries/SPI/src" "-I/home/dustin/src/arduino-1.8.3/hardware/arduino/avr/libraries/Wire/src" "/tmp/arduino_build_33309/sketch/healthypi3_streaming.ino.cpp" -o "/tmp/arduino_build_33309/sketch/healthypi3_streaming.ino.cpp.o"
healthypi3_streaming:58: error: 'sercom2' was not declared in this scope
 SPIClass ads1292rSPI (&sercom2, 4, 0, 1, SPI_PAD_2_SCK_3, SERCOM_RX_PAD_0);
                        ^
healthypi3_streaming:58: error: 'SPI_PAD_2_SCK_3' was not declared in this scope
 SPIClass ads1292rSPI (&sercom2, 4, 0, 1, SPI_PAD_2_SCK_3, SERCOM_RX_PAD_0);
                                          ^
healthypi3_streaming:58: error: 'SERCOM_RX_PAD_0' was not declared in this scope
 SPIClass ads1292rSPI (&sercom2, 4, 0, 1, SPI_PAD_2_SCK_3, SERCOM_RX_PAD_0);
                                                           ^
healthypi3_streaming:60: error: 'sercom0' was not declared in this scope
 SPIClass afe4490SPI (&sercom0, 17, 9 , 8, SPI_PAD_2_SCK_3, SERCOM_RX_PAD_0);
                       ^
healthypi3_streaming:60: error: 'SPI_PAD_2_SCK_3' was not declared in this scope
 SPIClass afe4490SPI (&sercom0, 17, 9 , 8, SPI_PAD_2_SCK_3, SERCOM_RX_PAD_0);
                                           ^
healthypi3_streaming:60: error: 'SERCOM_RX_PAD_0' was not declared in this scope
 SPIClass afe4490SPI (&sercom0, 17, 9 , 8, SPI_PAD_2_SCK_3, SERCOM_RX_PAD_0);
                                                            ^
healthypi3_streaming:62: error: 'Uart' does not name a type
 Uart  RpiSerial(&sercom4, 38, 22 , SERCOM_RX_PAD_1, UART_TX_PAD_0);
 ^
healthypi3_streaming:64: error: 'sercom1' was not declared in this scope
 TwoWire max30205(&sercom1, 11, 13);
                   ^
/home/dustin/src/healthypi-firmware/firmware/healthypi3_streaming/healthypi3_streaming.ino: In function 'void setup()':
healthypi3_streaming:271: error: 'SerialUSB' was not declared in this scope
     SerialUSB.begin(115200);
     ^
healthypi3_streaming:272: error: 'RpiSerial' was not declared in this scope
     RpiSerial.begin(57600);
     ^
/home/dustin/src/healthypi-firmware/firmware/healthypi3_streaming/healthypi3_streaming.ino: In function 'void loop()':
healthypi3_streaming:435: error: 'SerialUSB' was not declared in this scope
           SerialUSB.write(DataPacket[i]);
           ^
healthypi3_streaming:436: error: 'RpiSerial' was not declared in this scope
           RpiSerial.write(DataPacket[i]);
           ^
/home/dustin/src/healthypi-firmware/firmware/healthypi3_streaming/healthypi3_streaming.ino: In function 'void ads1292Rbegin()':
healthypi3_streaming:457: error: 'PIO_SERCOM_ALT' was not declared in this scope
    pinPeripheral(4, PIO_SERCOM_ALT);
                     ^
healthypi3_streaming:457: error: 'pinPeripheral' was not declared in this scope
    pinPeripheral(4, PIO_SERCOM_ALT);
                                   ^
/home/dustin/src/healthypi-firmware/firmware/healthypi3_streaming/healthypi3_streaming.ino: In function 'void afe4490begin()':
healthypi3_streaming:686: error: 'PIO_SERCOM_ALT' was not declared in this scope
     pinPeripheral(17, PIO_SERCOM_ALT);
                       ^
healthypi3_streaming:686: error: 'pinPeripheral' was not declared in this scope
     pinPeripheral(17, PIO_SERCOM_ALT);
                                     ^
/home/dustin/src/healthypi-firmware/firmware/healthypi3_streaming/healthypi3_streaming.ino: In function 'void max30205begin()':
healthypi3_streaming:757: error: 'PIO_SERCOM' was not declared in this scope
     pinPeripheral(11, PIO_SERCOM);
                       ^
healthypi3_streaming:757: error: 'pinPeripheral' was not declared in this scope
     pinPeripheral(11, PIO_SERCOM);
                                 ^
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
docmollo, 2017-08-10:
By the way, this is the firmware zip file from the v1.1 release.

VenkateshBhat, 2017-08-10:
@docmollo
Good day!
Please select the board as Arduino/Genuino zero(Native Port).

docmollo, 2017-08-10:
Yes, this was entirely user error. I woke up this morning and immediately realized what I had done last night. I made the change and everything worked as expected. Sorry for the trouble and thanks to @VenkateshBhat for the quick response!

Closed 2017-08-10.

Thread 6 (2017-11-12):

Usless after firmware update.

thejarle, 2017-11-12:
Hello.
I did a firmware upgrade (1.1) a while ago, and since then my helthypi3 has been useless. I have tried reinstalling the software on my pi (I got the v3 complete kit!), setting up a second pi with a fresh install and installed the heltypi software from scratch, tryd to get it working on both windows and Debian pc's with usb, but I get nothing. The firmware update was painless and everything looked fine. (I have done it twice to make sure) But since than I have not seen any info coming from my helthypi v3. Any help would be appreciated as I have tried everything I can think of.

VenkateshBhat, 2017-11-12:
@thejarle sorry for the inconvinience caused, could you please connect the HealthyPi board to the PC through USB port and check whether the USB is enumerating?

thejarle, 2017-11-12:

Mvh
Jarle Hansen

On Sun, Nov 12, 2017 at 4:20 AM, Venkatesh Bhat <notifications@github.com>
wrote:

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

VenkateshBhat, 2017-11-13:
Sorry I did not understand , please elaborate on this.

thejarle, 2017-11-13:
When I connect the Healthypi to the pc it shows like this in device
manager. Yes, I guess it "enumerates" (what ever that means?)

BR
Jarle

Mvh
Jarle Hansen

On Mon, Nov 13, 2017 at 2:06 PM, Venkatesh Bhat <notifications@github.com>
wrote:

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

VenkateshBhat, 2017-11-13:
Could you please attach the screenshot ?

thejarle, 2017-11-13:
Yes, here you are.

Jarle

Mvh
Jarle Hansen

On Mon, Nov 13, 2017 at 2:25 PM, Venkatesh Bhat <notifications@github.com>
wrote:

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

thejarle, 2017-11-15:
Hello again. Any idea . As I said: I have reinstalled my healthypi and
installed the software from scratch, but nothing works....

Jarle

On Mon, Nov 13, 2017 at 2:25 PM Venkatesh Bhat <notifications@github.com>
wrote:

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
--
Mvh
Jarle Hansen

VenkateshBhat, 2017-11-16:
@thejarle ,
I just want to ensure the USB port is enumerating, it would be helpful if you can share the screen shot of device manager page.

thejarle, 2017-11-16:
Yes, I have done it two times all ready !
Here it is one more time
It  is attached as a file called capture1.jpg.
If you somehow dont see it this time either it sais: Arduino Zero (com 2)
when I connect it.
I have tryeed setting it to different com ports. It was at com 16 in the
beginning.

Jarle

tor. 16. nov. 2017 kl. 06:16 skrev Venkatesh Bhat <notifications@github.com
>:

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

VenkateshBhat, 2017-11-16:
I still could not able to see, that is fine.
I presume that you are able to upload the program, could you please check in the serial monitor that data's are coming(HEX)?

thejarle, 2017-11-16:
I assume you are talking about the serial monitor in arduino ? I have never
used that. Can you please give me some instructions ?

Jarle

Mvh
Jarle Hansen

On Thu, Nov 16, 2017 at 10:23 AM, Venkatesh Bhat <notifications@github.com>
wrote:

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

thejarle, 2017-11-16:
I tryed to reflash the firmware again and everything looks ok when I do:

Sketch uses 25,708 bytes (9%) of program storage space. Maximum is 262,144
bytes.
Atmel SMART device 0x10010005 found
Device       : ATSAMD21G18A
Chip ID      : 10010005
Version      : v2.0 [Arduino:XYZ] Dec 20 2016 15:36:39
Address      : 8192
Pages        : 3968
Page Size    : 64 bytes
Total Size   : 248KB
Planes       : 1
Lock Regions : 16
Locked       : none
Security     : false
Boot Flash   : true
BOD          : true
BOR          : true
Arduino      : FAST_CHIP_ERASE
Arduino      : FAST_MULTI_PAGE_WRITE
Arduino      : CAN_CHECKSUM_MEMORY_BUFFER
Erase flash
done in 0.663 seconds

Write 26636 bytes to flash (417 pages)

[====                          ] 15% (64/417 pages)
[=========                     ] 30% (128/417 pages)
[=============                 ] 46% (192/417 pages)
[==================            ] 61% (256/417 pages)
[=======================       ] 76% (320/417 pages)
[===========================   ] 92% (384/417 pages)
[==============================] 100% (417/417 pages)
done in 0.167 seconds

Verify 26636 bytes of flash with checksum.
Verify successful
done in 0.027 seconds
CPU reset.

Mvh
Jarle Hansen

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

VenkateshBhat, 2017-11-17:
Please share your mail id.

thejarle, 2017-11-17:
Share my Mail id ? What do you mean? What Mail ID ?

Jarle

fre. 17. nov. 2017 kl. 08:24 skrev Venkatesh Bhat <notifications@github.com
>:

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
--
Mvh
Jarle Hansen

thejarle, 2017-11-17:
Do you mean the ID I usedvanlig when ordering the healtypy ? If that is
what you mean i think it was: jarle@theearl.net

Jarle

fre. 17. nov. 2017 kl. 08:24 skrev Venkatesh Bhat <notifications@github.com
>:

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
--
Mvh
Jarle Hansen

VenkateshBhat, 2017-11-17:
Your e-mail iD, I could able to see your attachment here.

thejarle, 2017-11-17:
you can use jarle@theearl.net or thejarle@gmail.com

Jarle

Mvh
Jarle Hansen

On Fri, Nov 17, 2017 at 9:18 AM, Venkatesh Bhat <notifications@github.com>
wrote:

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

Closed 2018-12-03.

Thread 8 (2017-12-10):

Trouble updating firmware from Linux Mint (64-bit) - 'sercom2' was not declared in this scope

BanjoFox, 2017-12-10:
Hey guys,
I've finally gotten around to trying out the firmware update for my HealthyPi with the touch screen.  However, when I run a check, in Arduino IDE I get an error:

'sercom2' was not declared in this scope

The system I am running on is a Linux Mint 64-bit machine, with Oracle Java 9 installed. I initially just had the healthypi hat plugged in (screen/pi powered off).  After seeing the error a second time I attached power to everything, and still had the PC direct to healthypi.  Same issue.

I might try on Windows 10 (64-bit as well), but I was wondering if I am missing something else.

Cheers!

Banjo

VenkateshBhat, 2017-12-10:
@BanjoFox
Please select board as Arduino Zero(Native Port)
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
let me know if you are still not able to rectify the error.

protocentralashwin, 2018-01-21:
@BanjoFox Did this solution work out for you?

BanjoFox, 2018-01-22:
Unfortunately no.
For some reason my laptop is not able to detect the HealthyPi board. Also tried it on Windows, but I believe my workstation is also not detecting the USB.  I believe that my workstation is USB 3 only though, which I seem to recall is not supported.

dpoleon, 2019-05-04:
Hi,

I am having trouble compiling the latest version of the code, I get the same error message.

Can you please help?

Regards

BanjoFox, 2020-10-09:
Hey
I FINALLY got around to trying this again, and I was able to get it resolved.  The 'sercom2' error was resolved by selecting the Arduino Native USB port, and also selecting the CORRECT COM port

Screenshot below.

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

joicetm, 2020-10-14:
We are glad that you were able to fix the problem.

Closed 2020-10-14.

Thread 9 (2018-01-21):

Firmware freezes when writing to RpiSerial

luzader, 2018-01-21:
The arduino firmware freezes at any call to RpiSerial.write(). As a result, after resetting only one reading is returned over USB, then nothing. If all calls to RpiSerial.write are removed, the HealthyPi3 works fine, though of course, only using USB. I saw the same effect on:
- Initial release plain text
- Initial release streaming
- v1.1 plain text
- v1.1 streaming

So this must be because of a change made by Arduino.

I would suspect that Arduino have changed the procedure for initializing the sercom4 and that the firmware is hanging on a check for transmission completed from the uart peripheral (unfortunately these operations never time out).

This might be what is causing #6

protocentralashwin, 2018-01-21:
Hi @luzader Thank you for the very detailed explanation. This makes sense, The sercom pins are not standard and the newer versions or libraries might be overriding this pin mapping is my guess. I will check this , work out an alternative and get  back. #6 also.

joicetm, 2018-01-22:
Hi luzader,

It seems the Board Manger Version is causing the issue(Not the arduino version, refer to the attached image )

Please try 1.6.15 which seems to give stable result.
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

joicetm, 2018-04-30:
Hope that your issue is solved.
you can reopen it whenever required.

kyokusei, 2018-11-27:
No, it doesn't work with 1.6.15
Furthermore, programming with USB I see only Native Port, and not Programming port as you says on your guideline for firmware update. So I've selected the Native USB Port from the board list.

anning865, 2020-01-16:
Finally, it works with 1.6.15
The issue should be highlighted at first.

Closed 2018-04-30.

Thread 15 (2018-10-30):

sphygmomanometer

QQ39272490, 2018-10-30:
I bought  healthypi v3. There are reserved BT_TX and BT_RX on the board. Just when we have developed the sphygmomanometer, we support UART. But I don't know how to use scom5 in Arduino zero, please enlighten me.  Email:39272490@qq.com
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

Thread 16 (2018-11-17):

useless firmware after update - me too!

xametxe, 2018-11-17:
Tried to modify firmware and upload it to my healthypi v3 using Arduino IDE. Uploading seems to work fine:
`Atmel SMART device 0x10010005 found
Device       : ATSAMD21G18A
Chip ID      : 10010005
Version      : v2.0 [Arduino:XYZ] Dec 20 2016 15:36:39
Address      : 8192
Pages        : 3968
Page Size    : 64 bytes
Total Size   : 248KB
Planes       : 1
Lock Regions : 16
Locked       : none
Security     : false
Boot Flash   : true
BOD          : true
BOR          : true
Arduino      : FAST_CHIP_ERASE
Arduino      : FAST_MULTI_PAGE_WRITE
Arduino      : CAN_CHECKSUM_MEMORY_BUFFER
Erase flash
done in 0.621 seconds

Write 27364 bytes to flash (428 pages)

[====                          ] 14% (64/428 pages)
[========                      ] 29% (128/428 pages)
[=============                 ] 44% (192/428 pages)
[=================             ] 59% (256/428 pages)
[======================        ] 74% (320/428 pages)
[==========================    ] 89% (384/428 pages)
[==============================] 100% (428/428 pages)
done in 0.166 seconds

Verify 27364 bytes of flash with checksum.
Verify successful
done in 0.028 seconds
CPU reset.`

Nevertheless, there is no data sent from the board and HealthypiGUI only shows flat lines.
I tried to also re-install the zero bootloader, but IDE shows the following error:
`Open On-Chip Debugger 0.9.0-g932ec70 (2017-02-15-11:32)
Licensed under GNU GPL v2
For bug reports, read
	http://openocd.org/doc/doxygen/bugs.html
debug_level: 0
adapter speed: 500 kHz
adapter_nsrst_delay: 100
cortex_m reset_config sysresetreq
Error: unable to find CMSIS-DAP device

Error burning bootloader`

I tried with different programmers (atmel-edbg, atmel-ice, atmelsam-ice, etc.) and different OSes (mac with El Capitan, ubuntu 16.04) without working.

So why doesn't it work? And how can I get my board running again?
Thank you in advance

xametxe, 2018-12-04:
It works! thnx

Closed 2018-12-04.

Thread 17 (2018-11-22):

Initial Screen

veronicamontoya, 2018-11-22:
Hi, I am having trouble with my Healthy Pi. I connected it properly, made sure everything was fine and updated, but once i copy the code on the terminal window, agree and reboot nothing shows up on the homescreen.  What can i do?

amafj, 2018-12-02:
I'm facing the same issue! did you solve it?

veronicamontoya, 2018-12-02:
1. Download processing on the raspberry
2. Download straight from the pi all the documents that appear on the
website
3. Once this is done, connect the pi through the usb cable that came with
it, do not connect it through the pins.
4. In the downloaded files, look for the file named healthy pi master (or
something like that). There is a file called gui, you select it and inside
there is a document called gui.pce and you run it through the processing
program.

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

amafj, 2018-12-02:
I've downloaded "processing" earlier, but  he problem is one I unzip the file nothing is extracted!

veronicamontoya, 2018-12-02:
Yes, same to me. I researched and found processing is a program, so I
downloaded the program in the raspberry. Then, when I unzipped the files I
went to the healthy master file. Once in there, I opened another file
called GUI, and in there is a doc called gui.pce. The gui.pce file is the
one you need to run through processing in order for the window to show up.

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

amafj, 2018-12-02:
dude are you on whatsapp or can I get ur email?

amafj, 2018-12-02:
because this thing is driving me crazy

veronicamontoya, 2018-12-02:
+504 9535 7977

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

archie020, 2018-12-03:
@veronicamontoya Kindly provide the following information for us to assess the issue:
1) Which Operating system are you using?
2) What method have you tried to install?
3) Have you purchased only the board or the entire unit including display?
4) Do attach the images or screenshots (for any errors)

archie020, 2018-12-03:
@amafj Kindly provide the following information for us to assess the issue:
1) Which Operating system are you using?
2) What method have you tried to install?
3) Have you purchased only the board or the entire unit including display?
4) Do attach the images or screenshots (for any errors)

amafj, 2018-12-05:
1- I'm using rasbian.
2- I've tried both methods, the advanced worked but I don't get any output. only a GUI.
3- Board and sensors only.
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

This is the output for running "healthypi3_gui_tcp.pde" codes.

Please help, the board is useless so far!!

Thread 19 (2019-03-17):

SPO2 not working

andrea1984, 2019-03-17:
There is some error on elaboration of SpO2, because the probe read the data correctly but the value of SPo2 cannot be computed. I attach some screenshot. I'm running firmware v2.0

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

Arif-healthyPi, 2021-03-29:
sir can you please tell me how to get sensors data on GUI window?

andrea1984, 2021-03-29:
Sorry but I don't have this hardware anymore, I cannot help you.

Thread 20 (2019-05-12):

Temperature Sensor Connection Order

dpoleon, 2019-05-12:
Hi, what is the correct wire connection order for the temperature sensor? There isn't a picture in the documentation.

Thanks.

joicetm, 2019-05-14:
Hi,
Please find attached image for temperature connection on healthy pi.

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

dpoleon, 2019-05-14:
Thank you, that is great...is there any chance that you could tell me which colours relate to which positions... I'm no electrician.

joicetm, 2019-05-14:
Hi,
Here i given color coding for temperature sensor connection,
RED-----------------VCC
GREEN--------------SCL
WHITE--------------SDA
BLACK--------------GND

dpoleon, 2019-05-14:
Perfect!...thank you for your quick response,   it is much appreciated!

Closed 2019-05-14.

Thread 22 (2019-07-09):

Fluctuating readings of ECG and Respiration

AkshayBh, 2019-07-09:
Hi!

I am trying to record the values from the Healthy Pi but the sensor data from the ECG probe is very fluctuating which is not very reliable. The Heart beat value fluctuates between 0 and some low value in range of 40-50 where 0 being the most frequent. While respiration value is upwards of 30.

I am attaching a screenshot of the GUI for further reference. The version is 1.1 for the firmware.
And I'm attaching the 3 lead electrode as mentioned in the diagram.

Can you help me as to figure out what might be the issue and how to solve it. And can you explain what are the values which get dumped in the .csv file.
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

Also attaching a .pdf which shows the rough values which Im able to log. Not able to understand what these values represent.
[exampleData.pdf](https://github.com/Protocentral/protocentral-healthypi-v3/files/3374946/exampleData.pdf)

gtyson, 2019-08-02:
We are trying to get a clean respiratory rate signal and it seems to be very noisy. We might try shielded EKG leads because the ones that come with the HealthyPi are pretty flimsy. Any other suggestions?

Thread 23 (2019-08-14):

Java PC code and streaming packet spec inconsistency?

tjurik, 2019-08-14:
I am trying to write my own code to read values from a healthyPi board (using a PC and the arduino driver)

I am interested in only the respiration rate.

When I look at the spec for the streaming packet format I see that it is offset 19 (see http://healthypi.protocentral.com/#streaming-packet-format)

When I look at the java code for the PC, it appears that the code does not follow protoxcol version 2. I note that there is a protocol version 3 here: https://github.com/Protocentral/protocentral_heartypatch/releases.  However, the packet format is not really explained well.

See the two attached images.

Spec version 02 explicitly lists the sub parts of the packets
Spec version 3 gives (from my perspective) ambiguous information for offsets 17-20 and 18+

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

Specifically - how does one determine the respiration rate with protocol version 0x03?
Protocol Version 0x02 has a specific value for it - but I can't find it in the spec for 3

Can someone explain to me which versions/where to get the latest and what the spec is for the protocol?

Alternatively, is there simple sample code to just pull the raw data from the packets (there is a page that mentions a python script)

Thanks
Tim

Adnan950, 2019-08-20:
hello,

I am also trying the same to get data from the healthy pi using python. I am kinda new to this, so I was thinking if you could help me with the code or we could work on it together.

I have gone through the firmware-update.md and advanced-healthypi.md but could not find a solution yet.

Looking forward for the reply.

Thanks
Adnan

Sannity, 2019-08-30:
I am looking for the same information. I have somewhat of a plan for what I might do to get the data, but from what is currently in the documentation it is not 100% clear.

If anybody has some insight or has done this already, I would appreciate any recommendations

Thanks
Austin

Adnan950, 2019-08-30:
Hello Austin,

I am Adnan and I was wonderinf if you could help me as you have some idea
of how to extract the data from healthy Pi v3. Looking forward to hearing
from you.

Thank you
Adnan

On Fri, 30 Aug 2019 at 07:37, Austin Monson <notifications@github.com>
wrote:

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

LeoMarHor, 2020-08-08:
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

Tim, the Hearty Patch is another hardware (https://www.crowdsupply.com/protocentral/heartypatch)
The latest firmware version for the Healthy Pi uses Protocol V2 and you can download it from this repo: https://github.com/Protocentral/protocentral-healthypi-v3/tree/v2.0

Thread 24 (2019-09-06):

API to connect with other softwares

jackyko1991, 2019-09-06:
It is nice to see such open source project and allow users to build a vital sign monitor with very low cost and research purpose.

I am currently working on ECG induced respiratory tracking project, this device really fits my work. However, my own program is written in Python/C++. Is there any documentation that I can get the vital signals from the device and stream to certain ports, let's say via usb, to allow me a further development?

jackyko1991, 2019-09-28:
Work with streaming packages, solved.

Closed 2019-09-28.

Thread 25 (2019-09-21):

How can I access the raw ECG data?

zhangshaohu, 2019-09-21:
I want to record the raw ECG data instead of HR. Do you have such an example to read the raw data? I am also wondering if I can wire the V3 board to an Arduino. If you can release the Java source code, it would be great!

jackyko1991, 2019-09-28:
you can get the raw ecg data via serial ports, i am working on python interfaces and you may take a look at my [repo](https://github.com/jackyko1991/HealthyPi-Python-Interface)

Streaming package info can be found [here](http://healthypi.protocentral.com/#streaming-packet-format)

tahamuneeb, 2020-04-03:
How can we read raw ecg value in same raspberry pi attached to healthy pi?

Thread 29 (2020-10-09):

No data from sensors

BanjoFox, 2020-10-09:
I am running into an issue where the sensors do not appear to be collecting any data.
the EEG is "--"
the O2 is"--"
the temperature is "--"

this is from the Windows GUI, and the Pi  touchscreen.

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

joicetm, 2020-10-14:
Hi,

When did it stopped working? after programming or something else ?
Is the led on spo2 probe is glowing ?
Are you getting any data on serial terminal ? try connecting to any serial terminal instead of connecting with gui. [baud rate = 115200 on windows]

if you tried to upload, what is the board selected on arduino? other upload configurations used on arduino ?

BanjoFox, 2020-10-14:
Hello,

It stopped reporting data after flashing the Firmware Update.  Even from the factory, I was having some troubles with it.
There is a red LED on the HAT itself.
I was not aware that there was a serial terminal.  Is that the same DB plug that the PulseOx connects to?
On the Arduino Studio the device selected is the Arduino Zero (Native).  I can get the full screenshot later.  When I do the uploads they appear to complete.  I do not recall if there are any warnings, but certainly there are no errors.

BanjoFox, 2020-10-17:
Here are screenshots of my Adruino Studio, and Serial output

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

BanjoFox, 2020-10-17:
I also just found this closed issue which looks to be related to mine

https://github.com/Protocentral/protocentral-healthypi-v3/issues/16

Is this the right board info (The latest version is 1.8.3)

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

Steveoyoung, 2020-12-07:
I have the same issue, brand new out of the box yesterday.  Stock firmware. Wasn't planning on learning the Arduino IDE.

Healthy Pi isn't cheap, anyone else have a solution not involving using refreshing Arduino?

Thanks

Steve

protocentralashwin, 2020-12-07:
@Steveoyoung Do you have the HealthyPi 3 or HealthyPi 4? Can you also please post a screenshot if possible?

Steveoyoung, 2020-12-07:
Ashwin,

Thanks for you quick reply,

Healthy Pi 4, connect3ed to a PI3.

Removed the serial stuff from cmdline.txt and added the overlay to the config.txt

Pulled out  of the box yesterday … any ideas?

Steven Young
steveoyoung@gmail.com

On Dec 7, 2020, at 9:42 AM, Ashwin K Whitchurch <notifications@github.com> wrote:

@Steveoyoung <https://github.com/Steveoyoung> Do you have the HealthyPi 3 or HealthyPi 4? Can you also please post a screenshot if possible?

—
You are receiving this because you were mentioned.
Reply to this email directly, view it on GitHub <https://github.com/Protocentral/protocentral-healthypi-v3/issues/29#issuecomment-740071833>, or unsubscribe <https://github.com/notifications/unsubscribe-auth/ALXEKIKXV4NQCEDU36WGTADSTUHZZANCNFSM4SKT6M3Q>.

Arif-healthyPi, 2021-03-28:
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

Thank you sir, you just solved my problem. Sir can you please tell me how to get the streams on gui window because i'm not able to find the port assign for healthy pi inside there. How can i get the readable form of sensors data?

Arif-healthyPi, 2021-03-28:
Thank you sir, you just solved my problem. Sir can you please tell me how to get the streams on gui window because i'm not able to find the port assign for healthy pi inside there. How can i get the readable form of sensors data?

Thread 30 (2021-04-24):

Healthypi v3 : "Could not resolve host" using curl -sS http://pi.protocentral.com/hpi3.sh | sudo bash

Allan0018, 2021-04-24:
I have purchased a healthypi v3 from before. Now, I'm trying to reinstall the firmware on my raspberrypi 3 B+ since my old sd card got corrupted.

However, the curl -sS http://pi.protocentral.com/hpi3.sh | sudo bash is no longer working, it says "could not resolve host".

I have tried the steps that pertain to the updated ver 4 which is curl -sS https://healthypi.protocentral.com/install.sh | sudo bash

I was able to install it but after the reboot nothing happen. Tried several times, nothing happened.

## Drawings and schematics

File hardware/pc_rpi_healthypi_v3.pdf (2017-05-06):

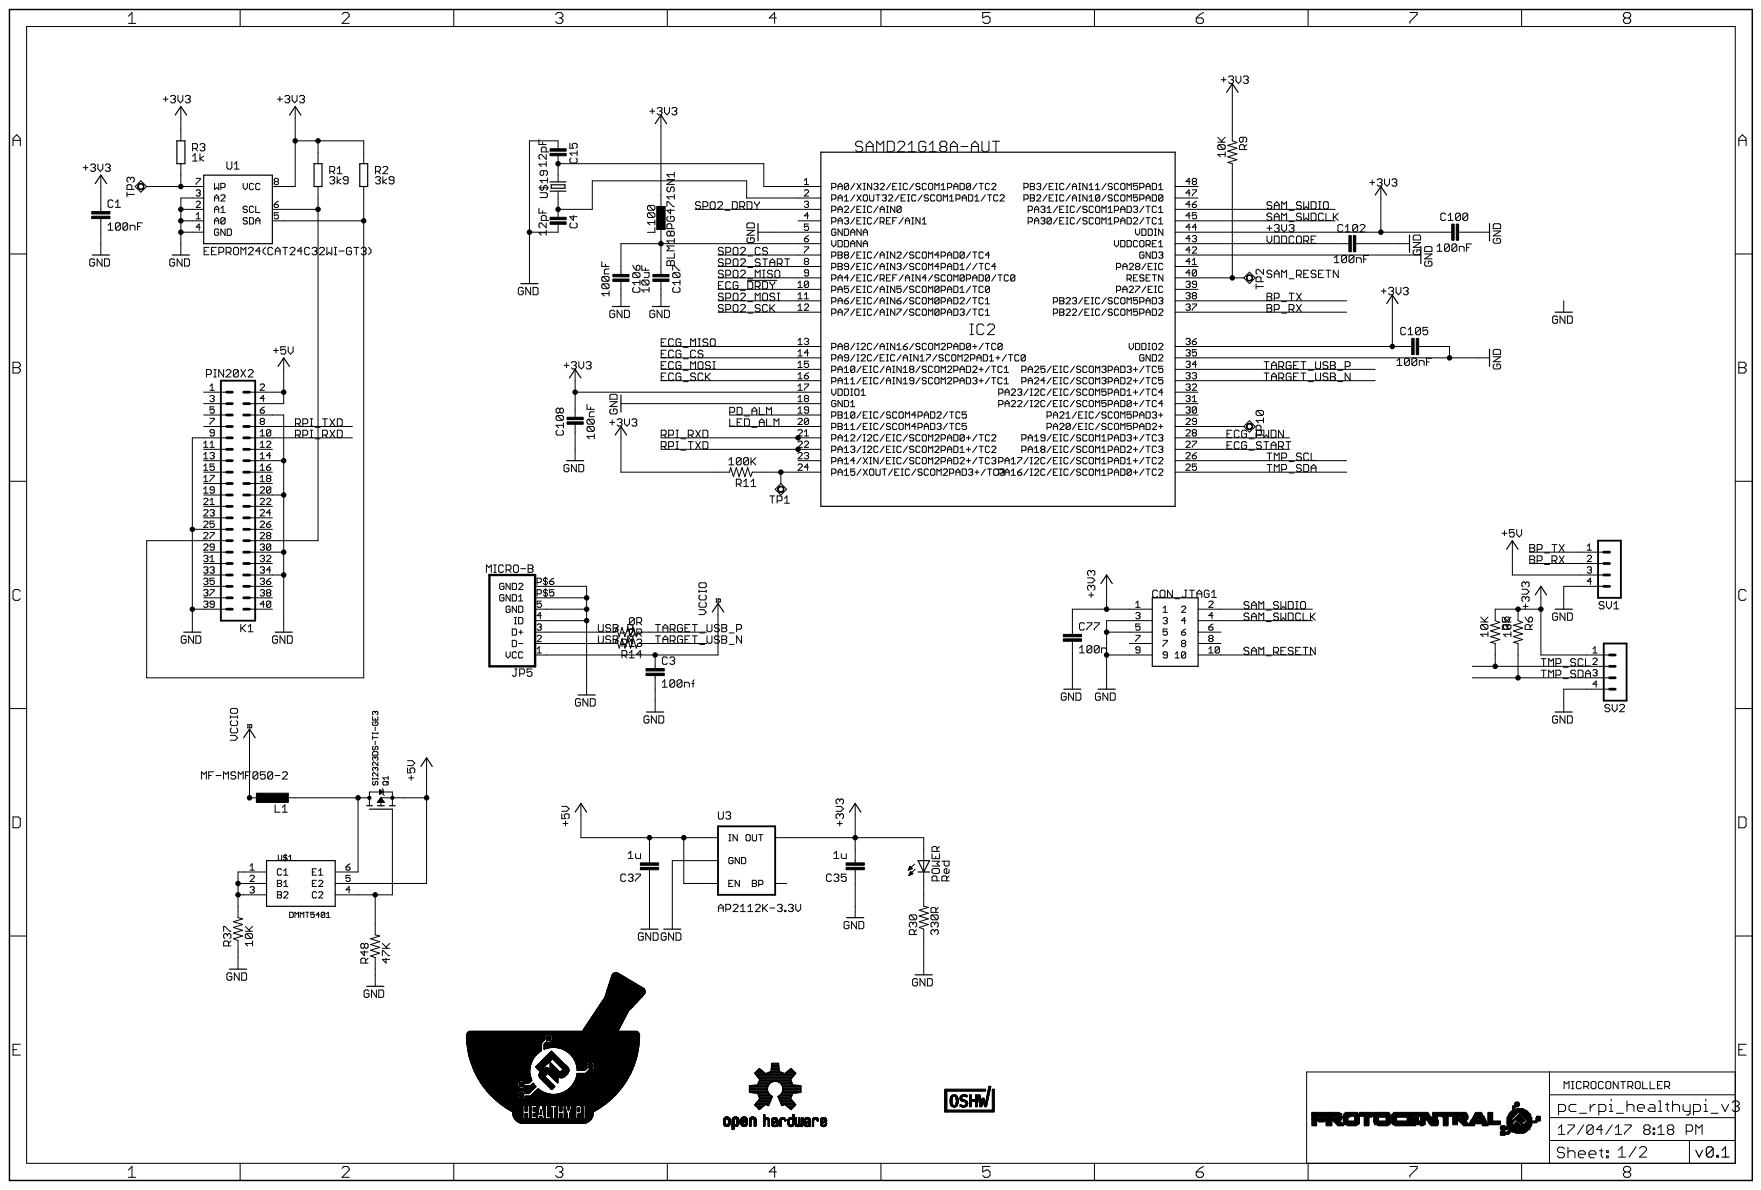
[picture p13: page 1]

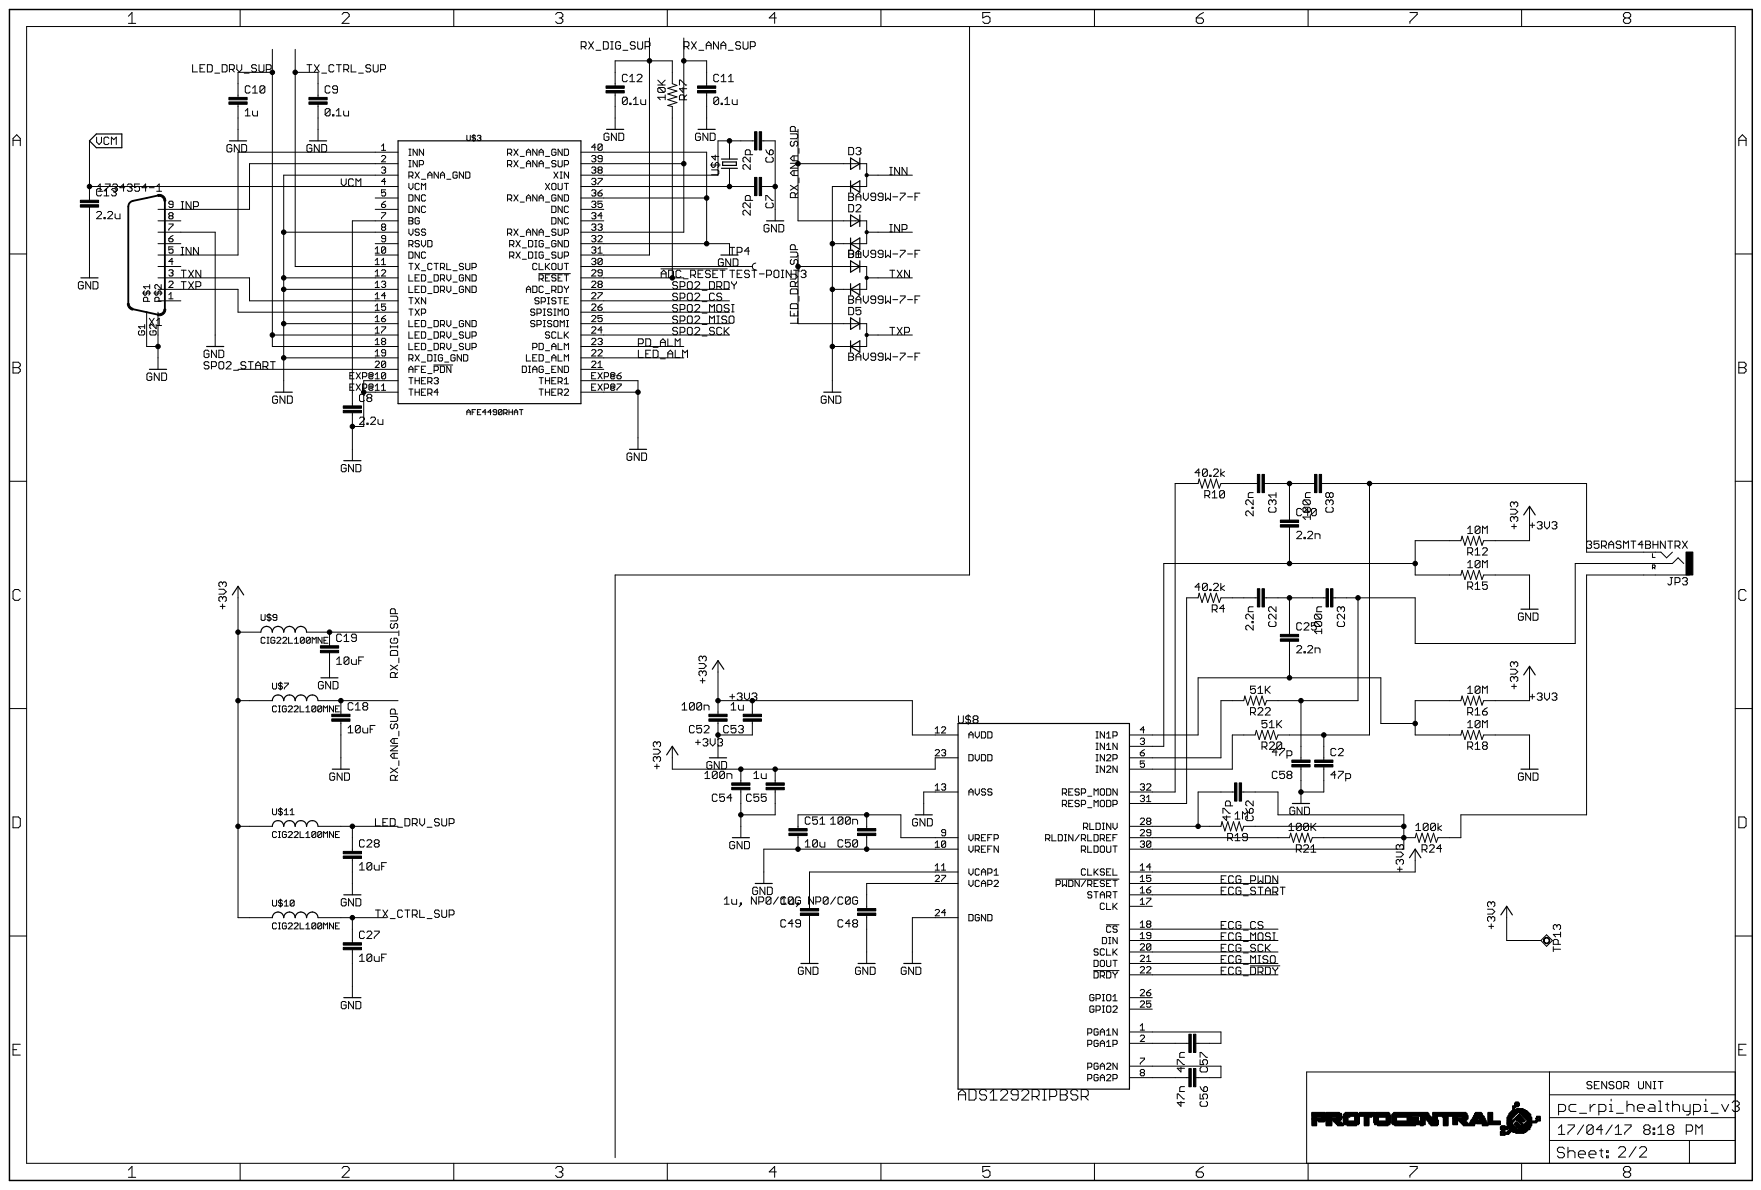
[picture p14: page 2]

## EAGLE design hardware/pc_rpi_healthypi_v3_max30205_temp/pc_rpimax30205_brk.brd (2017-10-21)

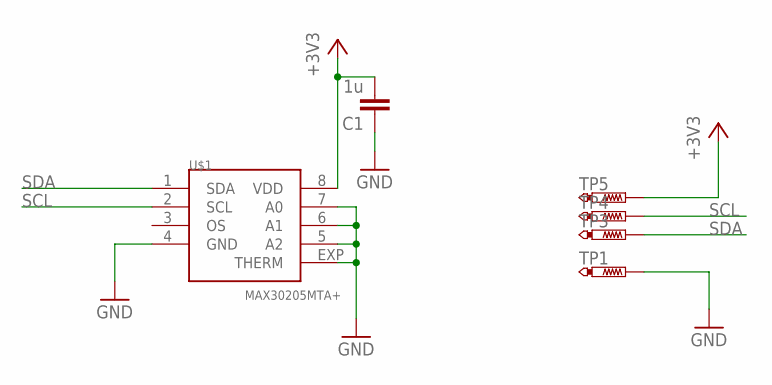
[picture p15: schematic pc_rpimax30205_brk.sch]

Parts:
C1: 1u; C0805
TP1, TP3, TP4, TP5: PTR1TP20SQ; TP20SQ
U$1: MAX30205MTA+; TDFN-08

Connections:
+3V3: C1.2, TP5.TP, U$1.8 (VDD)
GND: C1.1, TP1.TP, U$1.4 (GND), U$1.5 (A2), U$1.6 (A1), U$1.7 (A0), U$1.EXP (THERM)
SCL: TP4.TP, U$1.2 (SCL)
SDA: TP3.TP, U$1.1 (SDA)

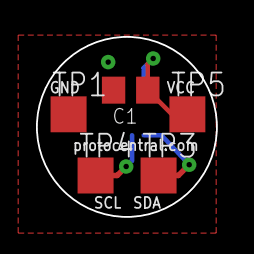
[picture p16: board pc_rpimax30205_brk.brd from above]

Board: 4 copper layers, 10.0 x 10.0 mm, 6 parts (1 on the bottom side), 4 nets.

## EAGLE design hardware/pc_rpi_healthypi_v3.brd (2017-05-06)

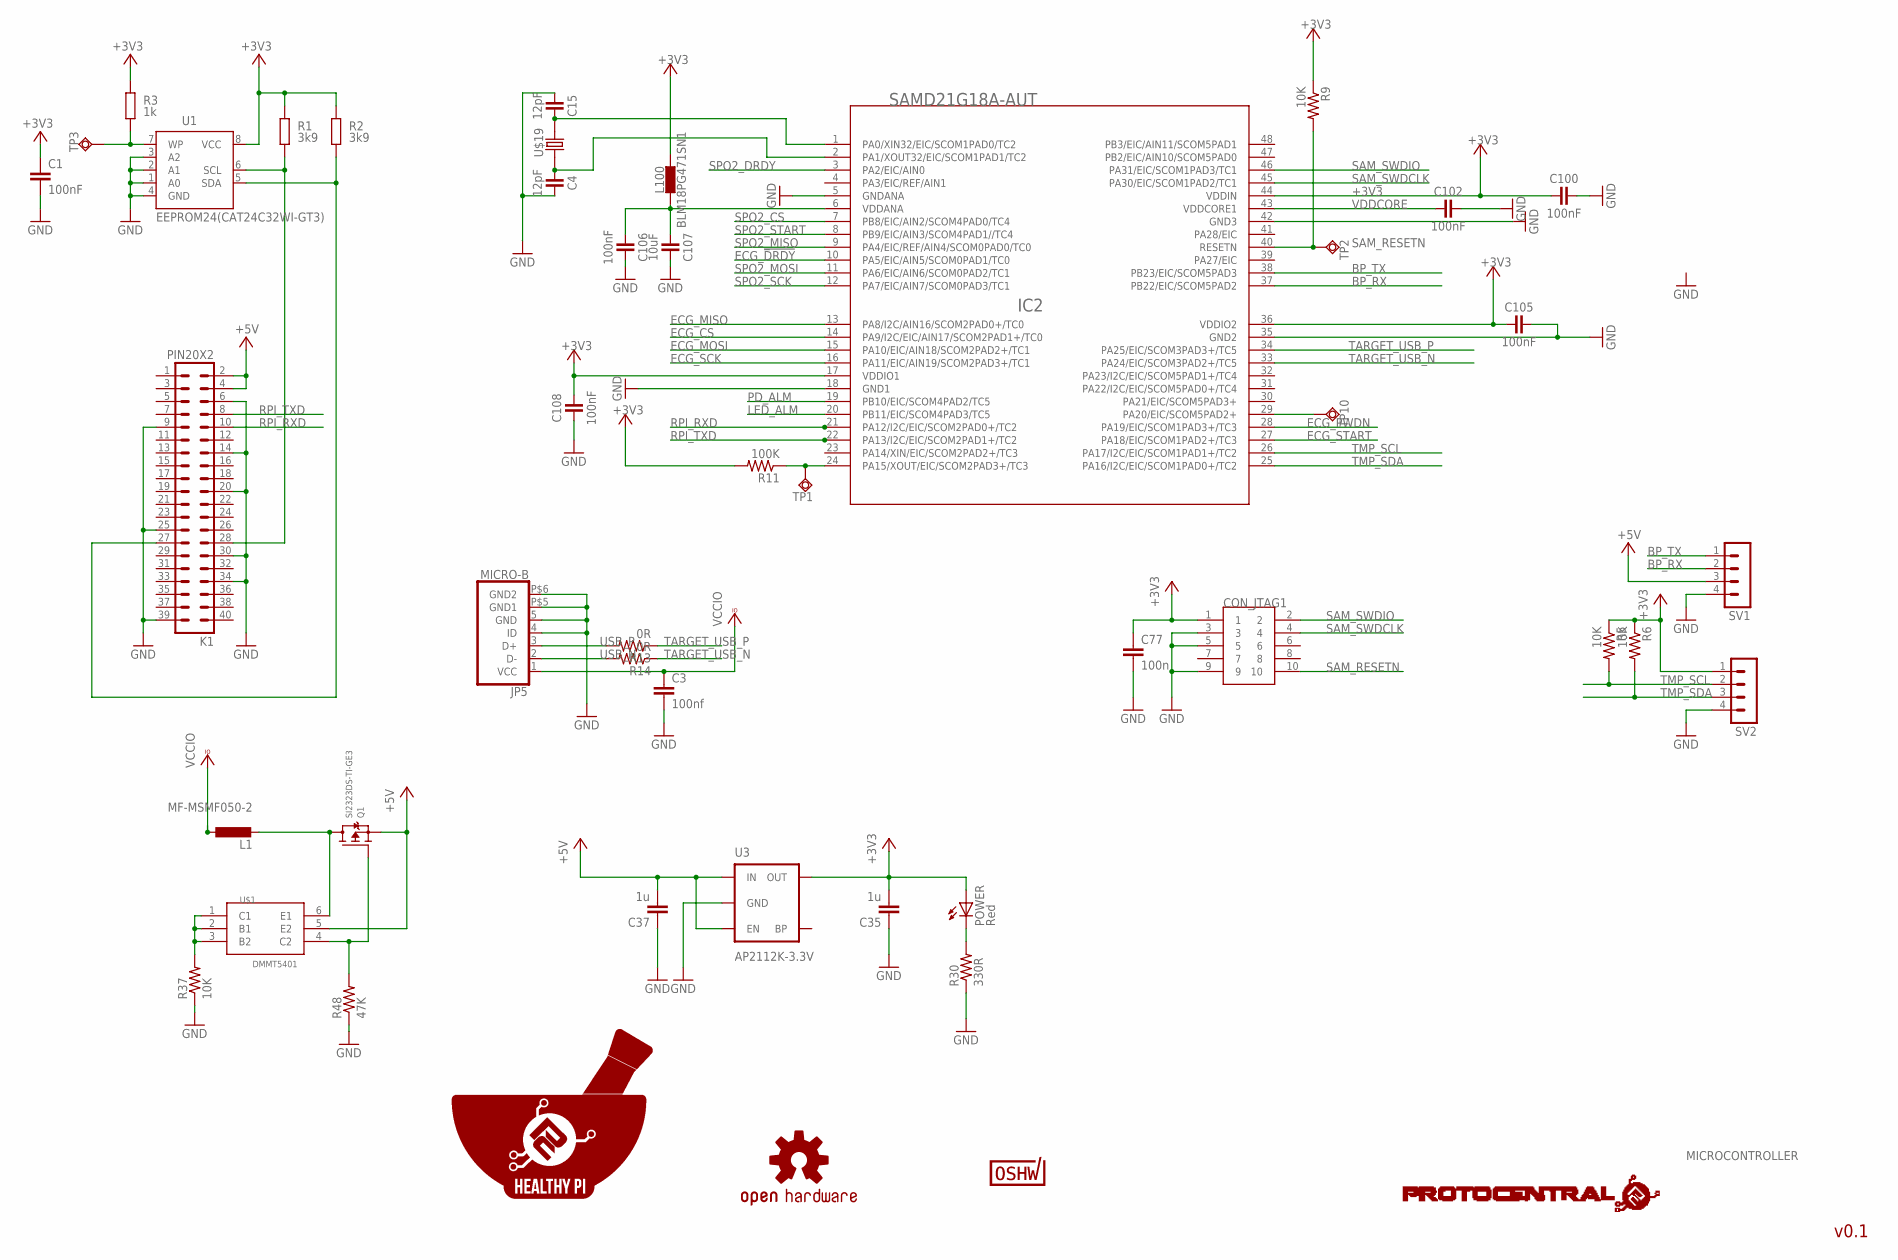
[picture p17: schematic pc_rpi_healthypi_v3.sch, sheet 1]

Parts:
C1: 100nF; C0805K
C3: 100nf; C0402
C4, C15: 12pF; C0402
C35, C37: 1u; C0402
C77: 100n; C0805
C100, C102, C105, C106, C108: 100nF; C0805
C107: 10uF; C0805
CON_JTAG1: HDR-SMT-50MIL/5X2(20021121-00010C4LF); HDR-SMT-50MIL/5X2
IC2: SAMD21G18A-AUT; TQFP48
JP5: MICRO-B
K1: PIN20X2; PIN_20X2
L1: MF-MSMF050-2; L1812
L100: BLM18PG471SN1; C0603
POWER: Red; CHIPLED_0603
Q1: SI2323DS-TI-GE3; SOT23-R
R1, R2: 3k9; M0805; TOLERANCE 5%
R3: 1k; M0805; TOLERANCE 5%
R5, R6: 10K; R0402
R9, R37: 10K; R0805
R11: 100K; R0805
R13, R14: 0R; R0402
R30: 330R; R0402
R48: 47K; R0805
SV1, SV2: MA04-1
TP1, TP2, TP3, TP10: TPSQB1,27; B1,27
U1: EEPROM24(CAT24C32WI-GT3); SOIC8
U3: AP2112K-3.3V; SOT23-5
U$1: DMMT5401; SOT26
U$5: OSHW-LOGOM; OSHW-LOGO-M
U$6: PROTY_LOGO_WITH_TEXT; PROTY_WITH_TEXT
U$13: CERT-SMALL; CERT-SMALL-SILK
U$15: HEALTHYPI
U$19: 520-327-12.5-34B(32.768KHZ); ECX-31B

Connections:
+3V3: C1.1, C35.2, C77.1, C100.1, C105.1, C108.2, CON_JTAG1.1, IC2.17 (VDDIO1), IC2.36 (VDDIO2), IC2.44 (VDDIN), L100.2, POWER.A, R1.2, R2.2, R3.2, R5.1, R6.1, R9.1, R11.2, SV2.1, U1.8 (VCC), U3.5 (OUT); also elsewhere on the board
+5V: C37.2, K1.2, K1.4, Q1.2 (S), SV1.3, U3.1 (IN), U3.3 (EN), U$1.5 (E2)
BP_RX: IC2.37 (PB22/EIC/SCOM5PAD2), SV1.2
BP_TX: IC2.38 (PB23/EIC/SCOM5PAD3), SV1.1
ECG_!DRDY: IC2.10 (PA5/EIC/AIN5/SCOM0PAD1/TC0); also elsewhere on the board
ECG_CS: IC2.14 (PA9/I2C/EIC/AIN17/SCOM2PAD1+/TC0); also elsewhere on the board
ECG_MISO: IC2.13 (PA8/I2C/AIN16/SCOM2PAD0+/TC0); also elsewhere on the board
ECG_MOSI: IC2.15 (PA10/EIC/AIN18/SCOM2PAD2+/TC1); also elsewhere on the board
ECG_PWDN: IC2.28 (PA19/EIC/SCOM1PAD3+/TC3); also elsewhere on the board
ECG_SCK: IC2.16 (PA11/EIC/AIN19/SCOM2PAD3+/TC1); also elsewhere on the board
ECG_START: IC2.27 (PA18/EIC/SCOM1PAD2+/TC3); also elsewhere on the board
GND: C1.2, C3.2, C4.2, C15.1, C35.1, C37.1, C77.2, C100.2, C102.2, C105.2, C106.2, C107.2, C108.1, CON_JTAG1.3, CON_JTAG1.5, CON_JTAG1.9, IC2.5 (GNDANA), IC2.18 (GND1), IC2.35 (GND2), IC2.42 (GND3), JP5.4 (ID), JP5.5 (GND), JP5.P$5 (GND1), JP5.P$6 (GND2), K1.6, K1.9, K1.14, K1.20, K1.25, K1.30, K1.34, K1.39, R30.1, R37.1, R48.1, SV1.4, SV2.4, U1.1 (A0), U1.2 (A1), U1.3 (A2), U1.4 (GND), U3.2 (GND); also elsewhere on the board
LED_ALM: IC2.20 (PB11/EIC/SCOM4PAD3/TC5); also elsewhere on the board
unnamed: K1.28, R1.1, U1.6 (SCL)
unnamed: K1.27, R2.1, U1.5 (SDA)
unnamed: R3.1, TP3.TP, U1.7 (WP)
unnamed: C15.2, IC2.1 (PA0/XIN32/EIC/SCOM1PAD0/TC2), U$19.P$2 (2)
unnamed: C106.1, C107.1, IC2.6 (VDDANA), L100.1
unnamed: POWER.C, R30.2
unnamed: C4.1, IC2.2 (PA1/XOUT32/EIC/SCOM1PAD1/TC2), U$19.P$1 (1)
unnamed: IC2.24 (PA15/XOUT/EIC/SCOM2PAD3+/TC3), R11.1, TP1.TP
unnamed: IC2.29 (PA20/EIC/SCOM5PAD2+), TP10.TP
unnamed: R37.2, U$1.1 (C1), U$1.2 (B1), U$1.3 (B2)
unnamed: Q1.1 (G), R48.2, U$1.4 (C2)
unnamed: L1.2, Q1.3 (D), U$1.6 (E1)
PD_ALM: IC2.19 (PB10/EIC/SCOM4PAD2/TC5); also elsewhere on the board
RPI_RXD: IC2.21 (PA12/I2C/EIC/SCOM2PAD0+/TC2), K1.10
RPI_TXD: IC2.22 (PA13/I2C/EIC/SCOM2PAD1+/TC2), K1.8
SAM_RESETN: CON_JTAG1.10, IC2.40 (RESETN), R9.2, TP2.TP
SAM_SWDCLK: CON_JTAG1.4, IC2.45 (PA30/EIC/SCOM1PAD2/TC1)
SAM_SWDIO: CON_JTAG1.2, IC2.46 (PA31/EIC/SCOM1PAD3/TC1)
SPO2_CS: IC2.7 (PB8/EIC/AIN2/SCOM4PAD0/TC4); also elsewhere on the board
SPO2_DRDY: IC2.3 (PA2/EIC/AIN0); also elsewhere on the board
SPO2_MISO: IC2.9 (PA4/EIC/REF/AIN4/SCOM0PAD0/TC0); also elsewhere on the board
SPO2_MOSI: IC2.11 (PA6/EIC/AIN6/SCOM0PAD2/TC1); also elsewhere on the board
SPO2_SCK: IC2.12 (PA7/EIC/AIN7/SCOM0PAD3/TC1); also elsewhere on the board
SPO2_START: IC2.8 (PB9/EIC/AIN3/SCOM4PAD1//TC4); also elsewhere on the board
TARGET_USB_N: IC2.33 (PA24/EIC/SCOM3PAD2+/TC5), R14.1
TARGET_USB_P: IC2.34 (PA25/EIC/SCOM3PAD3+/TC5), R13.1
TMP_SCL: IC2.26 (PA17/I2C/EIC/SCOM1PAD1+/TC2), R5.2, SV2.2
TMP_SDA: IC2.25 (PA16/I2C/EIC/SCOM1PAD0+/TC2), R6.2, SV2.3
USB_N: JP5.2 (D-), R14.2
USB_P: JP5.3 (D+), R13.2
VCCIO: C3.1, JP5.1 (VCC), L1.1
VDDCORE: C102.1, IC2.43 (VDDCORE1)

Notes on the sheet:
v0.1
MICROCONTROLLER

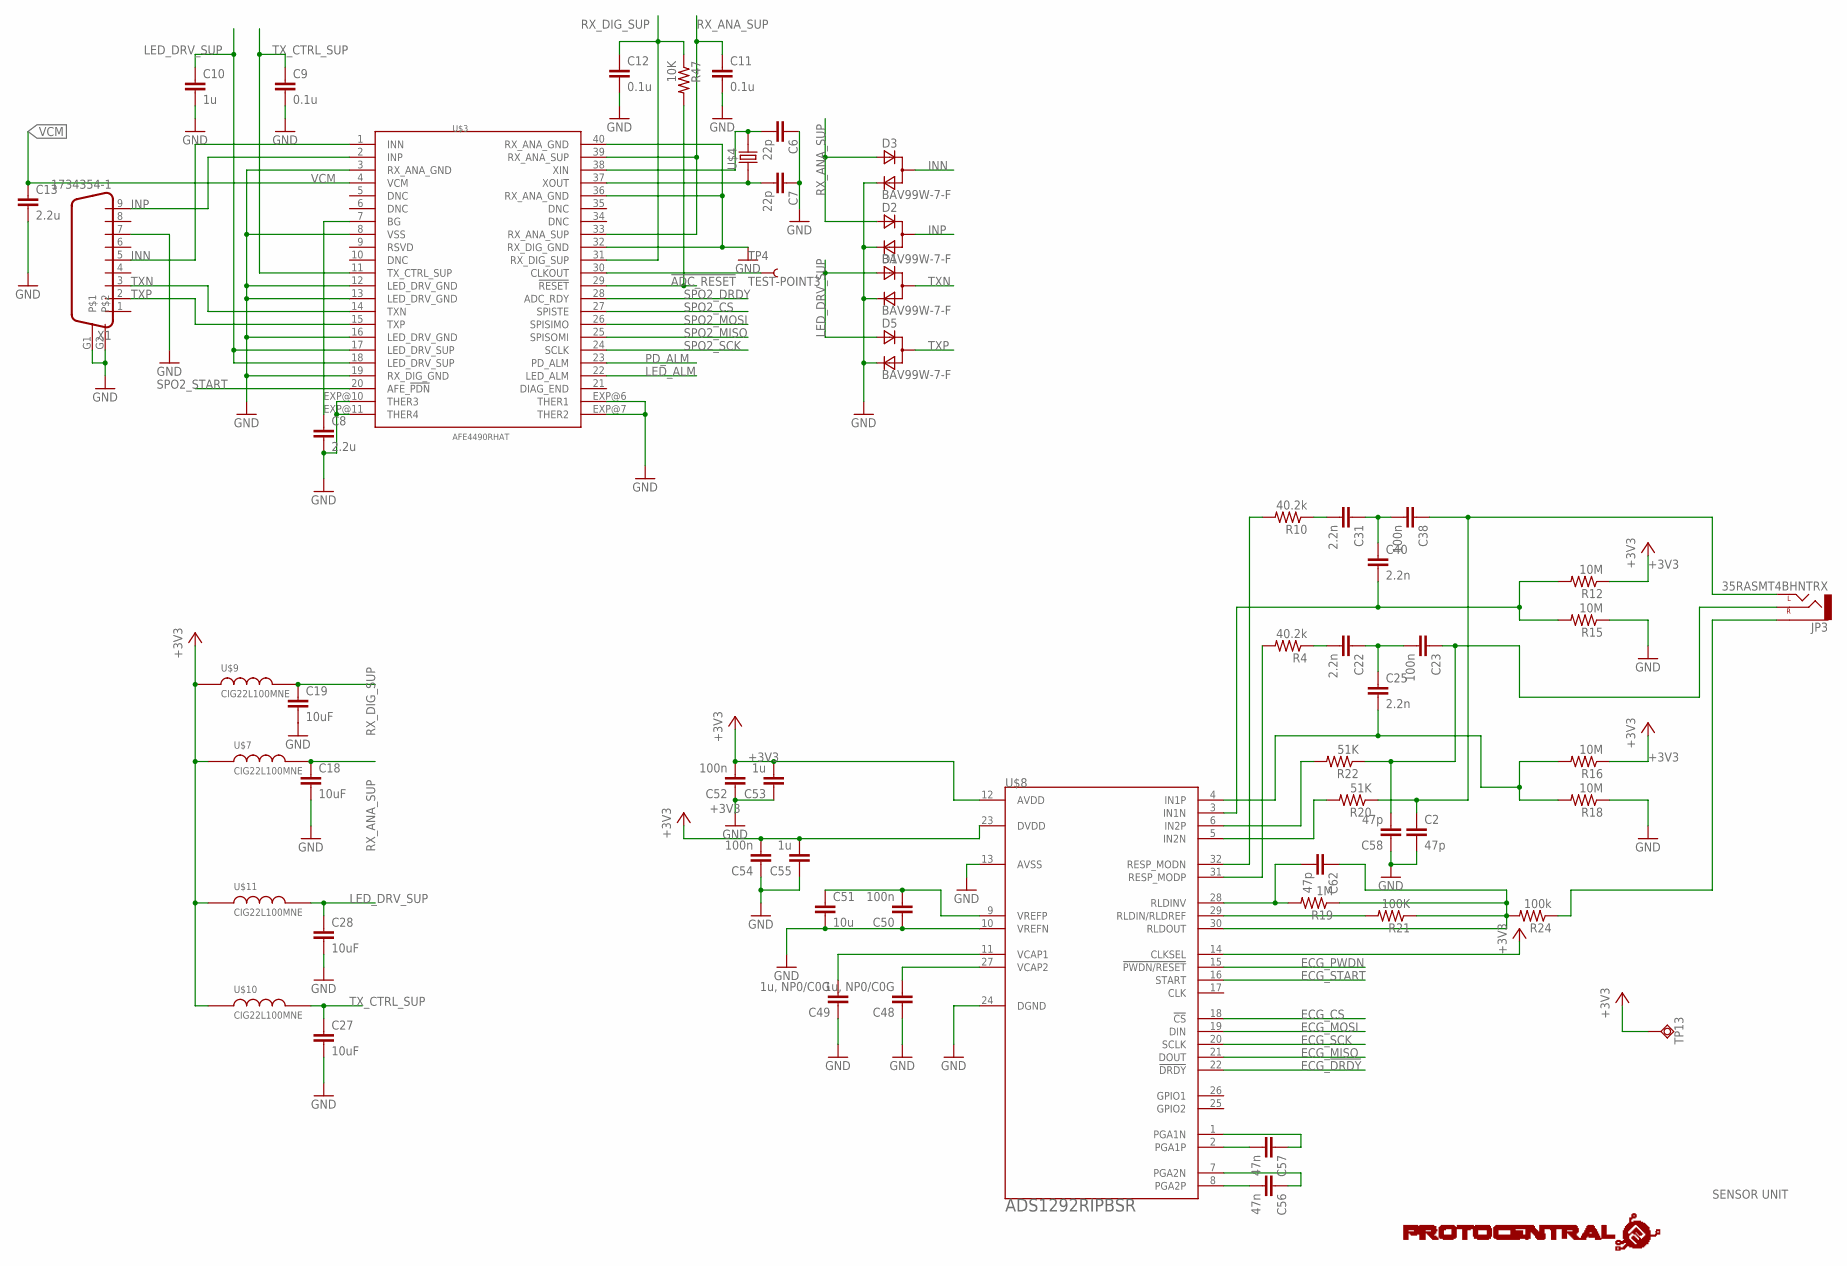
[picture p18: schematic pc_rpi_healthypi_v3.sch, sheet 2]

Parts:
C2, C58, C62: 47p; C0402
C6, C7: 22p; C0402
C8, C13: 2.2u; C0402
C9, C11, C12: 0.1u; C0402
C10: 1u; C0805
C18, C19, C27, C28: 10uF; C0805
C22, C25, C31, C40: 2.2n; C0402
C23, C38, C50, C52, C54: 100n; C0402
C48, C49: 1u, NP0/C0G; C0402
C51: 10u; C0603
C53, C55: 1u; C0402
C56, C57: 47n; C0402
D1, D2, D3, D5: BAV99W-7-F; SOT323
JP3: 35RASMT4BHNTRX; AUDIO-JACK-3.5MM-SMD
R4, R10: 40.2k; R0402
R12, R15, R16, R18: 10M; R0402
R19: 1M; R0402
R20, R22: 51K; R0402
R21: 100K; R0402
R24: 100k; R0402
R47: 10K; R0402
TP4: TEST-POINT3; PAD.03X.03
TP13: TPSQB1,27; B1,27
U$2: PROTY_LOGO_WITH_TEXT; PROTY_WITH_TEXT
U$3: AFE4490RHAT; QFN-40
U$4: ABM3
U$7, U$9, U$10, U$11: CIG22L100MNE; LPS
U$8: ADS1292RIPBSR; SQFP-S-5X5-32
X1: 1734354-1; DB9-STRIGHT

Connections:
!ADC_RESET: R47.2, U$3.29 (!RESET)
+3V3: C52.2, C53.2, C54.2, C55.2, R12.1, R16.1, TP13.TP, U$7.1, U$8.12 (AVDD), U$8.14 (CLKSEL), U$8.23 (DVDD), U$9.1, U$10.1, U$11.1; also elsewhere on the board
ECG_!DRDY: U$8.22 (!DRDY); also elsewhere on the board
ECG_CS: U$8.18 (!CS); also elsewhere on the board
ECG_MISO: U$8.21 (DOUT); also elsewhere on the board
ECG_MOSI: U$8.19 (DIN); also elsewhere on the board
ECG_PWDN: U$8.15 (!PWDN/RESET); also elsewhere on the board
ECG_SCK: U$8.20 (SCLK); also elsewhere on the board
ECG_START: U$8.16 (START); also elsewhere on the board
GND: C2.2, C6.1, C7.1, C8.2, C9.2, C10.2, C11.2, C12.2, C13.2, C18.2, C19.2, C27.2, C28.2, C48.1, C49.1, C50.1, C51.2, C52.1, C53.1, C54.1, C55.1, C58.1, D1.2 (C), D2.2 (C), D3.2 (C), D5.2 (C), R15.1, R18.1, U$3.3 (RX_ANA_GND), U$3.8 (VSS), U$3.12 (LED_DRV_GND), U$3.13 (LED_DRV_GND), U$3.16 (LED_DRV_GND), U$3.19 (RX_DIG_GND), U$3.32 (RX_DIG_GND), U$3.36 (RX_ANA_GND), U$3.40 (RX_ANA_GND), U$3.EXP@6 (THER1), U$3.EXP@7 (THER2), U$3.EXP@10 (THER3), U$3.EXP@11 (THER4), U$8.10 (VREFN), U$8.13 (AVSS), U$8.24 (DGND), X1.7, X1.G1, X1.G2; also elsewhere on the board
INN: D3.1 (CA), U$3.1 (INN), X1.5
INP: D2.1 (CA), U$3.2 (INP), X1.9
LED_ALM: U$3.22 (LED_ALM); also elsewhere on the board
LED_DRV_SUP: C10.1, C28.1, D1.3 (A), D5.3 (A), U$3.17 (LED_DRV_SUP), U$3.18 (LED_DRV_SUP), U$11.2
unnamed: R4.2, U$8.31 (RESP_MODP)
unnamed: C6.2, U$3.38 (XIN), U$4.2
unnamed: C22.2, R4.1
unnamed: C22.1, C23.2, C25.1
unnamed: R22.2, U$8.6 (IN2P)
unnamed: C7.2, U$3.37 (XOUT), U$4.1
unnamed: R20.2, U$8.5 (IN2N)
unnamed: C8.1, U$3.7 (BG)
unnamed: TP4.P$1, U$3.30 (CLKOUT)
unnamed: C48.2, U$8.27 (VCAP2)
unnamed: R10.2, U$8.32 (RESP_MODN)
unnamed: C31.2, R10.1
unnamed: C31.1, C38.2, C40.1
unnamed: C2.1, C38.1, JP3.TIP (LEFT), R20.1
unnamed: C40.2, R12.2, R15.2, U$8.3 (IN1N)
unnamed: C25.2, R16.2, R18.2, U$8.4 (IN1P)
unnamed: R21.2, U$8.29 (RLDIN/RLDREF)
unnamed: C62.2, R19.2, U$8.28 (RLDINV)
unnamed: C49.2, U$8.11 (VCAP1)
unnamed: C56.2, U$8.8 (PGA2P)
unnamed: C56.1, U$8.7 (PGA2N)
unnamed: C50.2, C51.1, U$8.9 (VREFP)
unnamed: C57.2, U$8.2 (PGA1P)
unnamed: C57.1, U$8.1 (PGA1N)
unnamed: C23.1, C58.2, JP3.RING (RIGHT), R22.1
unnamed: C62.1, R19.1, R21.1, R24.2, U$8.30 (RLDOUT)
unnamed: JP3.SLEEVE, R24.1
PD_ALM: U$3.23 (PD_ALM); also elsewhere on the board
RX_ANA_SUP: C11.1, C18.1, D2.3 (A), D3.3 (A), U$3.33 (RX_ANA_SUP), U$3.39 (RX_ANA_SUP), U$7.2
RX_DIG_SUP: C12.1, C19.1, R47.1, U$3.31 (RX_DIG_SUP), U$9.2
SPO2_CS: U$3.27 (SPISTE); also elsewhere on the board
SPO2_DRDY: U$3.28 (ADC_RDY); also elsewhere on the board
SPO2_MISO: U$3.25 (SPISOMI); also elsewhere on the board
SPO2_MOSI: U$3.26 (SPISIMO); also elsewhere on the board
SPO2_SCK: U$3.24 (SCLK); also elsewhere on the board
SPO2_START: U$3.20 (AFE_!PDN); also elsewhere on the board
TXN: D1.1 (CA), U$3.14 (TXN), X1.3
TXP: D5.1 (CA), U$3.15 (TXP), X1.2
TX_CTRL_SUP: C9.1, C27.1, U$3.11 (TX_CTRL_SUP), U$10.2
VCM: C13.1, U$3.4 (VCM)

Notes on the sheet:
SENSOR UNIT

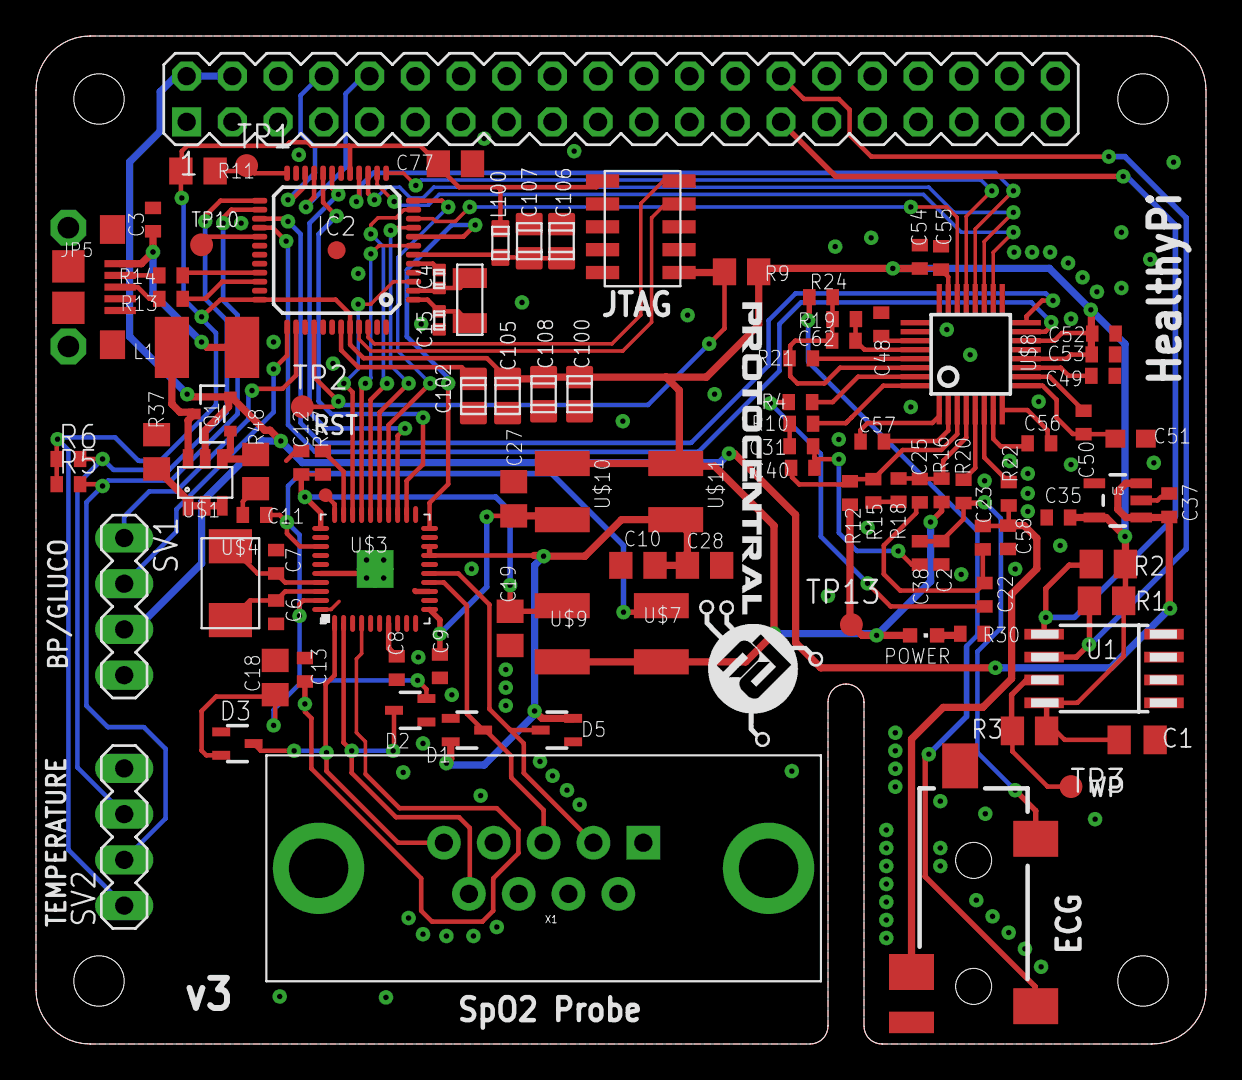
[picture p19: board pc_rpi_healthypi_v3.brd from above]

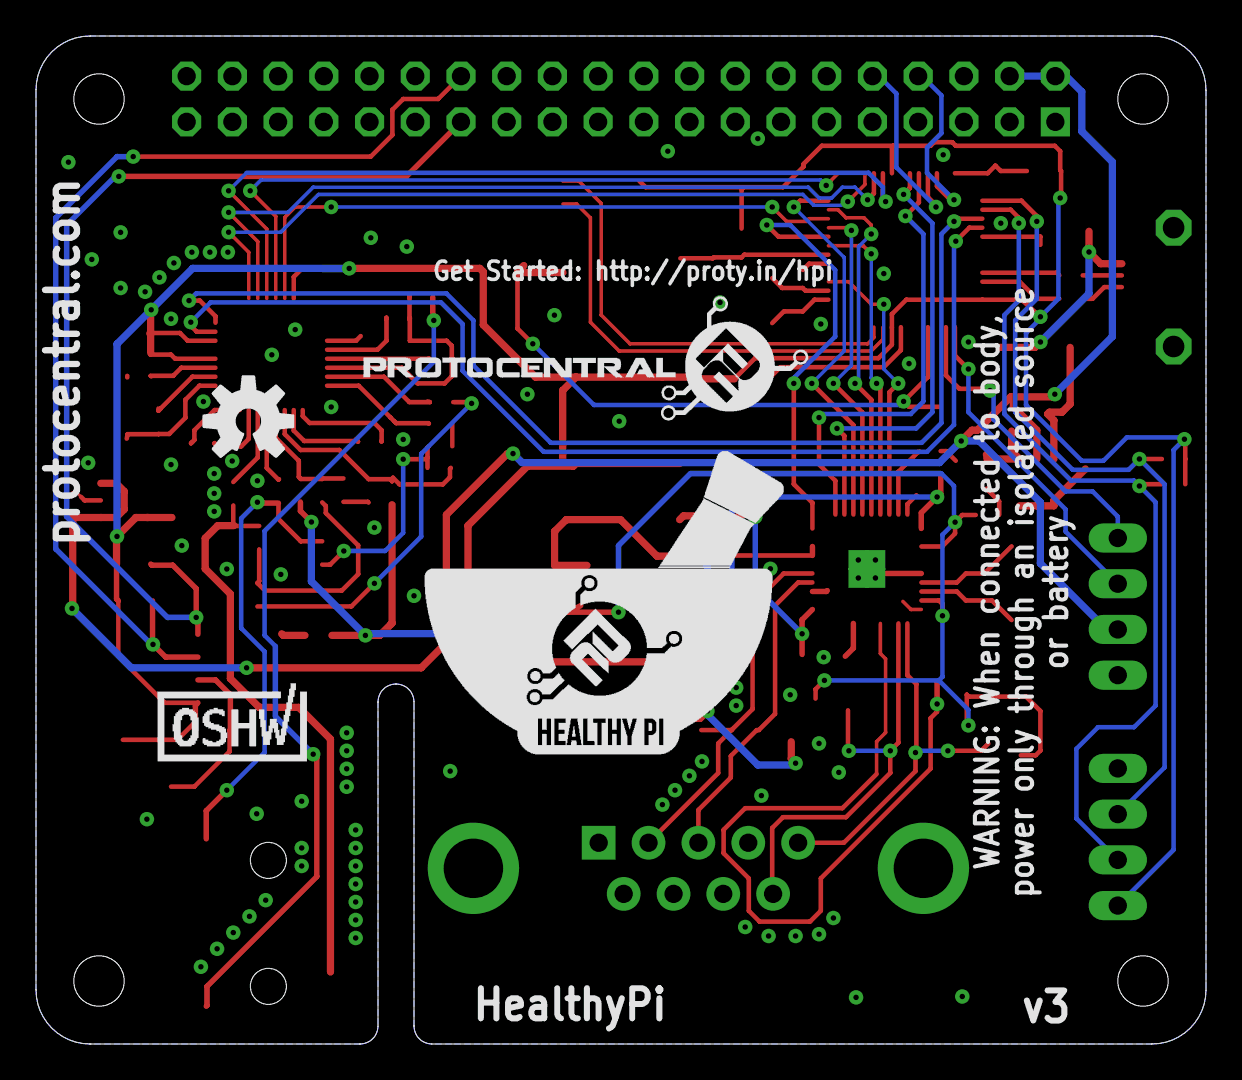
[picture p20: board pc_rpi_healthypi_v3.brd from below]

Board: 4 copper layers, 65.0 x 56.0 mm, 106 parts (4 on the bottom side), 82 nets.

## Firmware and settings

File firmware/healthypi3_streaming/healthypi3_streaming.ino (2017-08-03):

//////////////////////////////////////////////////////////////////////////////////////////
//
//   HealthyPi HAT v3 Arduino Firmware
//
//   Copyright (c) 2016 ProtoCentral
//   
//   Heartrate and respiration computation based on original code from Texas Instruments
//
//   SpO2 computation based on original code from Maxim Integrated 
//
//   This software is licensed under the MIT License(http://opensource.org/licenses/MIT). 
//   
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
//   For information on how to use the HealthyPi, visit https://github.com/protocentral/protocentral-healthypi-v3
/////////////////////////////////////////////////////////////////////////////////////////

#include <SPI.h>
#include <Wire.h>
#include "wiring_private.h" // pinPeripheral() function
#include "ads1292r.h"
#include "max30205.h"

#define TEMPERATURE 0
#define FILTERORDER         161
/* DC Removal Numerator Coeff*/
//#define NRCOEFF (0.992)
#define WAVE_SIZE  1
#define NRCOEFF (0.992)

#define IOPORT_PIN_LEVEL_HIGH 1
#define IOPORT_PIN_LEVEL_LOW 0

#define ADS1292R_CS_PIN   3
#define ADS1292R_START_PIN 10
#define ADS1292R_PWDN_PIN 12
#define ADS1292R_DRDY_PIN A4

#define AFE4490_START_PIN  16//A2
#define AFE4490_CS_PIN     15//A1
#define AFE4490_DRDY_PIN   A0 

//******* ecg filter *********
#define MAX_PEAK_TO_SEARCH         5
#define MAXIMA_SEARCH_WINDOW      40
#define MINIMUM_SKIP_WINDOW       50
#define SAMPLING_RATE             125
#define TWO_SEC_SAMPLES           2 * SAMPLING_RATE
#define QRS_THRESHOLD_FRACTION    0.4
#define TRUE 1
#define FALSE 0

//SPI class(MISO
SPIClass ads1292rSPI (&sercom2, 4, 0, 1, SPI_PAD_2_SCK_3, SERCOM_RX_PAD_0);
//SPI class(MISO
SPIClass afe4490SPI (&sercom0, 17, 9 , 8, SPI_PAD_2_SCK_3, SERCOM_RX_PAD_0);    
//SPI class(MISO
Uart  RpiSerial(&sercom4, 38, 22 , SERCOM_RX_PAD_1, UART_TX_PAD_0);    

TwoWire max30205(&sercom1, 11, 13);

int8_t NewDataAvailable;
uint8_t data_len = 20;

volatile byte MSB;
volatile byte data;
volatile byte LSB;

volatile byte *SPI_RX_Buff_Ptr;
unsigned long resultTemp = 0;
signed long sresultTemp,sresultTempResp ;
volatile float fresultTemp = 0;
volatile long iresultTemp = 0;
volatile long voltageTemp = 0;
volatile bool ads1292DataReceived = false;
volatile uint8_t  SPI_Dummy_Buff[10];
volatile long count=0;

uint8_t AFE4490_SPI_TX_Buff[10];
volatile uint8_t  AFE4490_SPI_RX_Buff[3]={0,0,0};
volatile uint32_t AFE4490resultTemp = 0;
volatile int32_t AFE4490sresultTempIR=0,AFE4490sresultTempRED=0;
volatile float AFE4490fresultTemp = 0;
volatile int32_t AFE4490iresultTemp = 0;
volatile int32_t AFE4490voltageTemp = 0;
volatile bool afe4490DataReceived = false;
long v[9];
long   sresultTempECG;
uint8_t heartRate_ads1292=0,heartRate_BP=0,spo2=0;

//************ filter ***************
uint8_t Respiration_Rate = 0 ;

int RESP_Second_Prev_Sample = 0 ;
int RESP_Prev_Sample = 0 ;
int RESP_Current_Sample = 0 ;
int RESP_Next_Sample = 0 ;
int RESP_Second_Next_Sample = 0 ;
uint16_t iprocess=0;

int16_t RESP_WorkingBuff[2 * FILTERORDER];
int16_t Pvev_DC_Sample=0, Pvev_Sample=0;
int16_t ECG_Pvev_DC_Sample, ECG_Pvev_Sample;

int16_t RespCoeffBuf[FILTERORDER] = 
{             
      /* Coeff for lowpass Fc=2Hz @ 125 SPS*/
      120,    124,    126,    127,    127,    125,    122,    118,    113,
      106,     97,     88,     77,     65,     52,     38,     24,      8,
       -8,    -25,    -42,    -59,    -76,    -93,   -110,   -126,   -142,
     -156,   -170,   -183,   -194,   -203,   -211,   -217,   -221,   -223,
     -223,   -220,   -215,   -208,   -198,   -185,   -170,   -152,   -132,
     -108,    -83,    -55,    -24,      8,     43,     80,    119,    159,
      201,    244,    288,    333,    378,    424,    470,    516,    561,
      606,    650,    693,    734,    773,    811,    847,    880,    911,
      939,    964,    986,   1005,   1020,   1033,   1041,   1047,   1049,
     1047,   1041,   1033,   1020,   1005,    986,    964,    939,    911,
      880,    847,    811,    773,    734,    693,    650,    606,    561,
      516,    470,    424,    378,    333,    288,    244,    201,    159,
      119,     80,     43,      8,    -24,    -55,    -83,   -108,   -132,
     -152,   -170,   -185,   -198,   -208,   -215,   -220,   -223,   -223,
     -221,   -217,   -211,   -203,   -194,   -183,   -170,   -156,   -142,
     -126,   -110,    -93,    -76,    -59,    -42,    -25,     -8,      8,
       24,     38,     52,     65,     77,     88,     97,    106,    113,
      118,    122,    125,    127,    127,    126,    124,    120      
};

int16_t CoeffBuf_40Hz_LowPass[FILTERORDER] = 
{
      -72,    122,    -31,    -99,    117,      0,   -121,    105,     34,
     -137,     84,     70,   -146,     55,    104,   -147,     20,    135,
     -137,    -21,    160,   -117,    -64,    177,    -87,   -108,    185,
      -48,   -151,    181,      0,   -188,    164,     54,   -218,    134,
      112,   -238,     90,    171,   -244,     33,    229,   -235,    -36,
      280,   -208,   -115,    322,   -161,   -203,    350,    -92,   -296,
      361,      0,   -391,    348,    117,   -486,    305,    264,   -577,
      225,    445,   -660,     93,    676,   -733,   -119,    991,   -793,
     -480,   1486,   -837,  -1226,   2561,   -865,  -4018,   9438,  20972,
     9438,  -4018,   -865,   2561,  -1226,   -837,   1486,   -480,   -793,
      991,   -119,   -733,    676,     93,   -660,    445,    225,   -577,
      264,    305,   -486,    117,    348,   -391,      0,    361,   -296,
      -92,    350,   -203,   -161,    322,   -115,   -208,    280,    -36,
     -235,    229,     33,   -244,    171,     90,   -238,    112,    134,
     -218,     54,    164,   -188,      0,    181,   -151,    -48,    185,
     -108,    -87,    177,    -64,   -117,    160,    -21,   -137,    135,
       20,   -147,    104,     55,   -146,     70,     84,   -137,     34,
      105,   -121,      0,    117,    -99,    -31,    122,    -72
};

volatile int16_t i16respbuff;
uint16_t resp_buff_indx=0;
int16_t res_wave_buff;
int16_t resp_filterout;
uint8_t    DataPacket[100];

uint16_t k=0;
uint8_t i = 0;

#define FS            25    //sampling frequency
#define BUFFER_SIZE  (FS*4) 
#define MA4_SIZE  4 // DONOT CHANGE
#define min(x,y) ((x) < (y) ? (x) : (y))

const uint8_t uch_spo2_table[184]={ 95, 95, 95, 96, 96, 96, 97, 97, 97, 97, 97, 98, 98, 98, 98, 98, 99, 99, 99, 99, 
              99, 99, 99, 99, 100, 100, 100, 100, 100, 100, 100, 100, 100, 100, 100, 100, 100, 100, 100, 100, 
              100, 100, 100, 100, 99, 99, 99, 99, 99, 99, 99, 99, 98, 98, 98, 98, 98, 98, 97, 97, 
              97, 97, 96, 96, 96, 96, 95, 95, 95, 94, 94, 94, 93, 93, 93, 92, 92, 92, 91, 91, 
              90, 90, 89, 89, 89, 88, 88, 87, 87, 86, 86, 85, 85, 84, 84, 83, 82, 82, 81, 81, 
              80, 80, 79, 78, 78, 77, 76, 76, 75, 74, 74, 73, 72, 72, 71, 70, 69, 69, 68, 67, 
              66, 66, 65, 64, 63, 62, 62, 61, 60, 59, 58, 57, 56, 56, 55, 54, 53, 52, 51, 50, 
              49, 48, 47, 46, 45, 44, 43, 42, 41, 40, 39, 38, 37, 36, 35, 34, 33, 31, 30, 29, 
              28, 27, 26, 25, 23, 22, 21, 20, 19, 17, 16, 15, 14, 12, 11, 10, 9, 7, 6, 5, 
              3, 2, 1 } ;
              
static  int32_t an_x[ BUFFER_SIZE]; 
static  int32_t an_y[ BUFFER_SIZE]; 

int16_t ECG_WorkingBuff[2 * FILTERORDER];
unsigned char Start_Sample_Count_Flag = 0;
unsigned char first_peak_detect = FALSE ;
unsigned int sample_index[MAX_PEAK_TO_SEARCH+2] ;
uint16_t scaled_result_display[150];
uint8_t indx =0;

int cnt =0;
volatile uint8_t flag =0;

int QRS_Second_Prev_Sample = 0 ;
int QRS_Prev_Sample = 0 ;
int QRS_Current_Sample = 0 ;
int QRS_Next_Sample = 0 ;
int QRS_Second_Next_Sample = 0 ;

static uint16_t QRS_B4_Buffer_ptr = 0 ;
int16_t QRS_Threshold_Old = 0;
int16_t QRS_Threshold_New = 0;
unsigned int sample_count = 0 ;

uint16_t QRS_Heart_Rate = 0 ;
int16_t ecg_wave_buff,ecg_filterout;

volatile uint8_t global_HeartRate=0;
volatile uint8_t global_RespirationRate=0;

uint16_t aun_ir_buffer[600]; //infrared LED sensor data
uint16_t aun_red_buffer[600];  //red LED sensor data

int32_t n_buffer_count; //data length

int32_t n_spo2;  //SPO2 value
int8_t ch_spo2_valid;  //indicator to show if the SPO2 calculation is valid
int32_t n_heart_rate; //heart rate value
int8_t  ch_hr_valid;  //indicator to show if the heart rate calculation is valid

long status_byte=0;
uint8_t LeadStatus=0;
boolean leadoff_deteted = true;
uint8_t spo2_probe_open = false;
long time_elapsed =0;

void ads1292_detection_callback(void)
{
    digitalWrite(ADS1292R_CS_PIN,LOW);

    for (int x = 0; x < 9 ; x++)
    {
      SPI_Dummy_Buff[x] = ads1292rSPI.transfer(0xff);
      // SerialUSB.print(SPI_Dummy_Buff[x],HEX); 
    }
    
    status_byte = (long)((long)SPI_Dummy_Buff[2] | ((long) SPI_Dummy_Buff[1]) <<8 | ((long) SPI_Dummy_Buff[0])<<16);
    status_byte  = (status_byte & 0x0f8000) >> 15;
    LeadStatus = (unsigned char ) status_byte ; 

    if(!((LeadStatus & 0x1f) == 0 ))
    leadoff_deteted  = TRUE;
    else leadoff_deteted  = FALSE;

    digitalWrite(ADS1292R_CS_PIN,HIGH);
    resultTemp = (unsigned long)((0x00 << 24) | (SPI_Dummy_Buff[6] << 16)| SPI_Dummy_Buff[7] << 8 | SPI_Dummy_Buff[8]);//6,7,8
    resultTemp = (unsigned long)(resultTemp << 8);

    sresultTemp = (signed long)(resultTemp);
    ecg_wave_buff = (int16_t)  (sresultTemp>>16);   // store for TI's algorithm
      
    resultTemp = (uint32_t)((0 << 24) | (SPI_Dummy_Buff[3] << 16)| SPI_Dummy_Buff[4] << 8 | SPI_Dummy_Buff[5]);//6,7,8
    resultTemp = (uint32_t)(resultTemp << 8);

    sresultTempResp = (long)(resultTemp);
    res_wave_buff = (int16_t)(sresultTempResp>>8) ; 
    
    ads1292DataReceived = true;
  
}
   
void afe4490_detection_callback(void)
{
   afe4490DataReceived = true;
   count++;
}

void setup() 
{   
    int cnt;
    delay(2000);
    
    SerialUSB.begin(115200);
    RpiSerial.begin(57600);
    
    max30205begin();
    
    ads1292Rbegin();
    delay(100);
    afe4490begin();   
    delay(500);
    AFE4490Write(CONTROL0,0x000001);
    n_buffer_count=0;


    for (cnt =0 ; cnt < FILTERORDER; cnt++)
    {
        RESP_WorkingBuff[cnt] = 0;
        ECG_WorkingBuff[cnt] = 0;
    }

    Pvev_DC_Sample = 0;
    Pvev_Sample = 0;
    ECG_Pvev_DC_Sample = 0;
    ECG_Pvev_Sample = 0;
}

int dec=0;

void loop() 
{   
   if(ads1292DataReceived == true)
   {
    if(leadoff_deteted == true)
     {
       if(millis() > time_elapsed )
       leadoff_deteted = true;
       else leadoff_deteted = false;
      
     }
     else
     {
        time_elapsed = millis() + 2000;
     }

     float temp = getTemperature()*100; // read temperature for every 100ms
     int temperature =  (uint16_t) temp;
       
      resp_filterout = Resp_ProcessCurrSample(res_wave_buff);
      //resp_filterout=res_wave_buff;
      RESP_Algorithm_Interface(resp_filterout);

      //ecg_filterout=ecg_wave_buff;
      ecg_filterout = ECG_ProcessCurrSample(ecg_wave_buff);
      QRS_Algorithm_Interface(ecg_filterout);
       
      DataPacket[0] = 0x0A;  // sync0
      DataPacket[1] = 0xFA;
      DataPacket[2] = (uint8_t) (data_len);
      DataPacket[3] = (uint8_t) (data_len>>8);
      DataPacket[4] = 0x02;
      
      if(leadoff_deteted == true)
      {
            DataPacket[5] = 0;
          DataPacket[6] =  0;
    
          DataPacket[7] =  0;
          DataPacket[8] =  0;
      }
      else
      {
          DataPacket[5] =  ecg_filterout;
          DataPacket[6] =  ecg_filterout>>8;
    
          DataPacket[7] =  resp_filterout;
          DataPacket[8] =  resp_filterout>>8;   
      }

      if(1) // if(afe4490DataReceived == true)
      {     
          AFE4490_SPI_TX_Buff[0] =  0x2C;
          
          digitalWrite(AFE4490_CS_PIN,LOW);
          afe4490SPI.transfer(AFE4490_SPI_TX_Buff[0]);
          
          AFE4490_SPI_RX_Buff[0] =  afe4490SPI.transfer(0xff);
          AFE4490_SPI_RX_Buff[1] =  afe4490SPI.transfer(0xff);
          AFE4490_SPI_RX_Buff[2] =  afe4490SPI.transfer(0xff);
          
          AFE4490resultTemp = (uint32_t)( ((0x00 << 24) | AFE4490_SPI_RX_Buff[0] << 16)| AFE4490_SPI_RX_Buff[1] << 8 | AFE4490_SPI_RX_Buff[2]);
          AFE4490resultTemp = (uint32_t)(AFE4490resultTemp << 10);

          if(dec==5)
          {
            aun_ir_buffer[n_buffer_count]=(uint16_t) (AFE4490resultTemp>>16);
          }
          
          AFE4490sresultTempIR = (int32_t)(AFE4490resultTemp );
          //AFE4490sresultTempIR = (AFE4490sresultTempIR);// * 100;
          
          AFE4490_SPI_TX_Buff[0] =  0x2A;
          
          afe4490SPI.transfer(AFE4490_SPI_TX_Buff[0]);
          
          AFE4490_SPI_RX_Buff[0] =  afe4490SPI.transfer(0xff);
          AFE4490_SPI_RX_Buff[1] =  afe4490SPI.transfer(0xff);
          AFE4490_SPI_RX_Buff[2] =  afe4490SPI.transfer(0xff);
          
          AFE4490resultTemp = (uint32_t)( ((0x00 << 24) | AFE4490_SPI_RX_Buff[0] << 16)| AFE4490_SPI_RX_Buff[1] << 8 | AFE4490_SPI_RX_Buff[2]);
          AFE4490resultTemp = (uint32_t)(AFE4490resultTemp << 10);

          if(dec==5)
          {
           aun_red_buffer[n_buffer_count]=(uint16_t) (AFE4490resultTemp>>16);
           dec=0;
            n_buffer_count++;
          }
          
          dec++;
           
          AFE4490sresultTempRED = (int32_t)(AFE4490resultTemp );
          AFE4490sresultTempRED = (AFE4490sresultTempRED >> 10);// * 100;   
          
          digitalWrite(AFE4490_CS_PIN,HIGH);
 
          if(n_buffer_count>99)
          {
            
            estimate_spo2(aun_ir_buffer, 100, aun_red_buffer, &n_spo2, &ch_spo2_valid); 
            if(n_spo2 == -999)
            spo2_probe_open = true;
            else
            spo2_probe_open = false;
            
            n_buffer_count=0;
          }         
      }  
      
      DataPacket[9] =  AFE4490sresultTempIR;  // spo2 ir
      DataPacket[10] =  AFE4490sresultTempIR>>8;
      DataPacket[11] =  AFE4490sresultTempIR>>16;
      DataPacket[12] =  AFE4490sresultTempIR>>24;

      DataPacket[13] =  AFE4490sresultTempRED;  // spo2 ir
      DataPacket[14] =  AFE4490sresultTempRED>>8;
      DataPacket[15] =  AFE4490sresultTempRED>>16;
      DataPacket[16] =  AFE4490sresultTempRED>>24;

      DataPacket[17] =  (uint8_t) temperature;      // temperature
      DataPacket[18] =  (uint8_t) (temperature >> 8);
        
      DataPacket[19] =  global_RespirationRate; //QRS_Heart_Rate;   // calculated from ads1292r
      DataPacket[20] =  n_spo2;
  
      DataPacket[21] =  global_HeartRate;   // systolic pressure
      DataPacket[22] =  80;     //diastolic pressure
      DataPacket[23] =  heartRate_BP;  // from BP module

      DataPacket[24] =    spo2_probe_open<< 1 |leadoff_deteted;  // leadstatus
        
      DataPacket[25] = 0x00;
      DataPacket[26] = 0x0b;
    
      for(int i=0; i<27; i++) // transmit the data
      {
          SerialUSB.write(DataPacket[i]);
          RpiSerial.write(DataPacket[i]);        
      } 
      ads1292DataReceived = false;
  }
}

void ads1292Rbegin()
{

  ads1292rSPI.begin();
  

  pinMode(ADS1292R_START_PIN, OUTPUT);
  pinMode(ADS1292R_DRDY_PIN, INPUT);
  pinMode(ADS1292R_DRDY_PIN, INPUT_PULLUP);
  attachInterrupt(ADS1292R_DRDY_PIN, ads1292_detection_callback , FALLING);
  pinMode(ADS1292R_PWDN_PIN, OUTPUT);

  
  pinMode(ADS1292R_CS_PIN, OUTPUT);
 
   pinPeripheral(4, PIO_SERCOM_ALT);
   pinPeripheral(0, PIO_SERCOM_ALT);
   pinPeripheral(1, PIO_SERCOM_ALT);
  
   ads1292rSPI.beginTransaction(SPISettings(1000000, MSBFIRST, SPI_MODE1));
  
  SPI_Reset();                                            
  delay(100);       

  ADS1292_Disable_Start();
  delay(100);                                               

  ADS1292_Enable_Start();
  delay(10);  

 
  ADS1292_Hard_Stop();
  ADS1292_Start_Data_Conv_Command();
  ADS1292_Soft_Stop(); 

  digitalWrite(ADS1292R_CS_PIN,LOW);

  ADS1292_Reg_Write(0x01,0x00);     //Set sampling rate to 125 SPS
  delay(10);
  
  ADS1292_Reg_Write(0x02,0b11100000); //Lead-off comp off, test signal disabled
  delay(10);
  ADS1292_Reg_Write(0x03,0b11110000); //Lead-off defaults
  delay(10);
  ADS1292_Reg_Write(0x04,0b01000000);   //Ch 1 enabled, gain 6, connected to electrode in
  delay(10);
  ADS1292_Reg_Write(0x05,0b01100000);   //Ch 2 enabled, gain 6, connected to electrode in
  delay(10);
  ADS1292_Reg_Write(0x06,0b00101100); //RLD settings: fmod/16, RLD enabled, RLD inputs from Ch2 only
  delay(10);
  ADS1292_Reg_Write(0x07,0x00);   //LOFF settings: all disabled
  delay(10);
  //Skip register 8, LOFF Settings default
  
  ADS1292_Reg_Write(0x09,0b11110010); //Respiration: MOD/DEMOD turned only, phase 0
  delay(10);
  ADS1292_Reg_Write(0x0A,0b00000011); //Respiration: Calib OFF, respiration freq defaults
  delay(10);

  ADS1292_Enable_Start();
  
  ADS1292_Start_Read_Data_Continuous();
  
  digitalWrite(ADS1292R_CS_PIN,HIGH); //release chip, signal end transfer

  SPI_Start();
  delay(100);
}

void writeRegister(uint8_t address, uint8_t value)
{
  digitalWrite(ADS1292R_CS_PIN,LOW);
  delay(5);
  ads1292rSPI.transfer(WREG|(address<<2));        
  ads1292rSPI.transfer(value); 
  delay(5);
  digitalWrite(ADS1292R_CS_PIN,HIGH);
}  


uint8_t readRegister(uint8_t address)
{
  uint8_t data;

  digitalWrite(ADS1292R_CS_PIN,LOW);
  delay(5);
  ads1292rSPI.transfer(RREG|(address<<2));        
//  data = ads1292rSPI.transfer(SPI_MASTER_DUMMY); 
  delay(5);
  digitalWrite(ADS1292R_CS_PIN,HIGH);

  return data;
}  

uint8_t * Read_Data()
{
  static byte SPI_Buff[3];

  if((digitalRead(ADS1292R_DRDY_PIN)) == LOW)                //        Wait for DRDY to transition low
  {
    digitalWrite(ADS1292R_CS_PIN,LOW);                          //Take CS low
    delayMicroseconds(100);
    for (int i = 0; i < 3; i++)
    { 
     // SPI_Buff[i] = ads1292rSPI.transfer(SPI_MASTER_DUMMY);
    }
    delayMicroseconds(100);
    digitalWrite(ADS1292R_CS_PIN,HIGH);                      //  Clear CS to high
    NewDataAvailable = true;
  }
    
  return SPI_Buff;
}

void SPI_Reset()
{
  digitalWrite(ADS1292R_PWDN_PIN, IOPORT_PIN_LEVEL_HIGH);
  delay(20);
  digitalWrite(ADS1292R_PWDN_PIN, IOPORT_PIN_LEVEL_LOW);
  delay(20);
  digitalWrite(ADS1292R_PWDN_PIN, IOPORT_PIN_LEVEL_HIGH);
  delay(20); 
  ADS1292_SPI_Command_Data(RESET);                              
}

void SPI_Start()
{
  ADS1292_SPI_Command_Data(START);
}

void SPI_Stop()
{
  ADS1292_SPI_Command_Data(STOP);
}

void ADS1292_Reg_Write (unsigned char READ_WRITE_ADDRESS, unsigned char DATA)
{
  uint8_t  SPI_TX_Buff[10];
  
  switch (READ_WRITE_ADDRESS)
  {
  
    case 1: DATA = DATA & 0x87;
        break;
        
    case 2: DATA = DATA & 0xFB;
        DATA |= 0x80;
        break;
        
    case 3: DATA = DATA & 0xFD;
        DATA |= 0x10;
        break;
        
    case 7: DATA = DATA & 0x3F;
        break;
        
    case 8: DATA = DATA & 0x5F;
        break;
        
    case 9:DATA |= 0x02;
        break;
        
    case 10:DATA = DATA & 0x87;
        DATA |= 0x01;
        break;
        
    case 11:DATA = DATA & 0x0F;
        break;
        
    default:break;
  }   
  
  SPI_TX_Buff[0] = READ_WRITE_ADDRESS | WREG;
  SPI_TX_Buff[1] = 0;           // Write Single byte
  SPI_TX_Buff[2] = DATA;          // Write Single byte         // Write Single byte

  digitalWrite(ADS1292R_CS_PIN,LOW);
  delay(5);
  ads1292rSPI.transfer( SPI_TX_Buff[0]);        
  ads1292rSPI.transfer(SPI_TX_Buff[1]); 
  ads1292rSPI.transfer(SPI_TX_Buff[2]); 
  delay(5);
  digitalWrite(ADS1292R_CS_PIN,HIGH);
}

void ADS1292_Enable_Start(void)
{
  digitalWrite(ADS1292R_START_PIN, IOPORT_PIN_LEVEL_HIGH);
  delay(20);
}

void ADS1292_Disable_Start(void)
{
  digitalWrite(ADS1292R_START_PIN, IOPORT_PIN_LEVEL_LOW);
  delay(20);
}

void ADS1292_Hard_Stop (void)
{
  digitalWrite(ADS1292R_START_PIN, IOPORT_PIN_LEVEL_LOW);
  delay(100);
}

void ADS1292_Start_Data_Conv_Command (void)
{
  ADS1292_SPI_Command_Data(START);
}

void ADS1292_Soft_Stop (void)
{
  ADS1292_SPI_Command_Data(STOP);  
}

void ADS1292_Start_Read_Data_Continuous (void)
{
  ADS1292_SPI_Command_Data(RDATAC);         // Send 0x10 to the ADS1x9x
}


void ADS1292_SPI_Command_Data(unsigned char data_in)
{
  digitalWrite(ADS1292R_CS_PIN, LOW);
  delay(2);
  digitalWrite(ADS1292R_CS_PIN, HIGH);
  delay(2);
  digitalWrite(ADS1292R_CS_PIN, LOW);
  delay(2);
  ads1292rSPI.transfer(data_in);
  delay(2);
  digitalWrite(ADS1292R_CS_PIN, HIGH);
}
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

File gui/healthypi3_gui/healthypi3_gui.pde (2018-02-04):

//////////////////////////////////////////////////////////////////////////////////////////
//
//   Raspberry Pi/ Desktop GUI for controlling the HealthyPi HAT v3
//
//   Copyright (c) 2016 ProtoCentral
//   
//   This software is licensed under the MIT License(http://opensource.org/licenses/MIT). 
//   
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
/////////////////////////////////////////////////////////////////////////////////////////

import g4p_controls.*;                       // Processing GUI Library to create buttons, dropdown,etc.,
import processing.serial.*;                  // Serial Library
import grafica.*;

// Java Swing Package For prompting message
import java.awt.*;
import javax.swing.*;
import static javax.swing.JOptionPane.*;

// File Packages to record the data into a text file
import javax.swing.JFileChooser;
import java.io.FileWriter;
import java.io.BufferedWriter;

// Date Format
import java.util.*;
import java.text.DateFormat;
import java.text.SimpleDateFormat;

// General Java Package
import java.math.*;
import controlP5.*;
import mqtt.*;
import org.eclipse.paho.client.mqttv3.MqttException;

MQTTClient client;
ControlP5 cp5;

String default_mqtt_server = "io.adafruit.com";
String default_mqtt_username = "akw";
String default_mqtt_password = "4746bf5b83de4d5db4e4c03ad8b304cd";
int mqtt_post_interval=5000; //millisecond

Textlabel lblHR;
Textlabel lblSPO2;
Textlabel lblRR;
Textlabel lblBP;
Textlabel lblTemp;
Textlabel lblMQTT;
Textlabel lblMQTTStatus;

/************** Packet Validation  **********************/
private static final int CESState_Init = 0;
private static final int CESState_SOF1_Found = 1;
private static final int CESState_SOF2_Found = 2;
private static final int CESState_PktLen_Found = 3;

/*CES CMD IF Packet Format*/
private static final int CES_CMDIF_PKT_START_1 = 0x0A;
private static final int CES_CMDIF_PKT_START_2 = 0xFA;
private static final int CES_CMDIF_PKT_STOP = 0x0B;

/*CES CMD IF Packet Indices*/
private static final int CES_CMDIF_IND_LEN = 2;
private static final int CES_CMDIF_IND_LEN_MSB = 3;
private static final int CES_CMDIF_IND_PKTTYPE = 4;
private static int CES_CMDIF_PKT_OVERHEAD = 5;

/************** Packet Related Variables **********************/

int ecs_rx_state = 0;                                        // To check the state of the packet
int CES_Pkt_Len;                                             // To store the Packet Length Deatils
int CES_Pkt_Pos_Counter, CES_Data_Counter;                   // Packet and data counter
int CES_Pkt_PktType;                                         // To store the Packet Type
char CES_Pkt_Data_Counter[] = new char[1000];                // Buffer to store the data from the packet
char CES_Pkt_ECG_Counter[] = new char[4];                    // Buffer to hold ECG data
char CES_Pkt_Resp_Counter[] = new char[4];                   // Respiration Buffer
char CES_Pkt_SpO2_Counter_RED[] = new char[4];               // Buffer for SpO2 RED
char CES_Pkt_SpO2_Counter_IR[] = new char[4];                // Buffer for SpO2 IR
int pSize = 1000;                                            // Total Size of the buffer
int arrayIndex = 0;                                          // Increment Variable for the buffer
float time = 0;                                              // X axis increment variable

// Buffer for ecg,spo2,respiration,and average of thos values
float[] xdata = new float[pSize];
float[] ecgdata = new float[pSize];
float[] respdata = new float[pSize];
float[] bpmArray = new float[pSize];
float[] ecg_avg = new float[pSize];                          
float[] resp_avg = new float[pSize];
float[] spo2data = new float[pSize];
float[] spo2Array_IR = new float[pSize];
float[] spo2Array_RED = new float[pSize];
float[] rpmArray = new float[pSize];
float[] ppgArray = new float[pSize];

/************** Graph Related Variables **********************/

double maxe, mine, maxr, minr, maxs, mins;             // To Calculate the Minimum and Maximum of the Buffer
double ecg, resp, spo2_ir, spo2_red, spo2, redAvg, irAvg, ecgAvg, resAvg;  // To store the current ecg value
double respirationVoltage=20;                          // To store the current respiration value
boolean startPlot = false;                             // Conditional Variable to start and stop the plot

GPlot plotPPG;
GPlot plotECG;
GPlot plotResp;

int step = 0;
int stepsPerCycle = 100;
int lastStepTime = 0;
boolean clockwise = true;
float scale = 5;

/************** File Related Variables **********************/

boolean logging = false;                                // Variable to check whether to record the data or not
FileWriter output;                                      // In-built writer class object to write the data to file
JFileChooser jFileChooser;                              // Helps to choose particular folder to save the file
Date date;                                              // Variables to record the date related values                              
BufferedWriter bufferedWriter;
DateFormat dateFormat;

/************** Port Related Variables **********************/

Serial port = null;                                     // Oject for communicating via serial port
String[] comList;                                       // Buffer that holds the serial ports that are paired to the laptop
char inString = '\0';                                   // To receive the bytes from the packet
String selectedPort;                                    // Holds the selected port number

/************** Logo Related Variables **********************/

PImage logo;
boolean gStatus;                                        // Boolean variable to save the grid visibility status

int nPoints1 = pSize;
int totalPlotsHeight=0;
int totalPlotsWidth=0;
int heightHeader=100;
int updateCounter=0;

boolean is_raspberrypi=false;

int global_hr;
int global_rr;
float global_temp;
int global_spo2;

int global_test=0;

boolean ECG_leadOff,spo2_leadOff;
boolean ShowWarning = true;
boolean ShowWarningSpo2=true;

boolean mqtt_on=false;
int mqtt_post_start_time=0;
int mqtt_post_stop_time=0;

int mqtt_hr=0;
int mqtt_rr=0;
int mqtt_spo2=0;
float mqtt_temp=0;

Accordion accordion;

String mqtt_server;
String mqtt_username;
String mqtt_password;
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

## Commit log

2017-05-06 Init commit
    [pc_rpi_healthypi_v3.brd, pc_rpi_healthypi_v3.sch]
2017-05-27 updated arduino code for v3
    included max30205 temperature sensor
2017-06-01 Updated Arduino main firmware
2017-07-14 Updated docs main board image
2017-07-16 Added assembly videos for complete kit and USB standalone
2017-07-19 Updated new file structure
    [Fit Patch Assly Organic Covers - 33.stl]
2017-08-02 Added new firmware
    Bug fixes in heart rate and respiration rate algorithm
    [healthypi3_gui.pde, healthypi3_streaming.ino]
2017-08-03 Corrected afe44xx naming, removed header file
    [healthypi3_streaming.ino, healthypi3_text_only.ino]
2017-10-21 Added temperature sensor board schematics
    [pc_rpimax30205_brk.brd, pc_rpimax30205_brk.sch]
2018-02-04 Corrected MQTT feed data
    [healthypi3_gui.pde]

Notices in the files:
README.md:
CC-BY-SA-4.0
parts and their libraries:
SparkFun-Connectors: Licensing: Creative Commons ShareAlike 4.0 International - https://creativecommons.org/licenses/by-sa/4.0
